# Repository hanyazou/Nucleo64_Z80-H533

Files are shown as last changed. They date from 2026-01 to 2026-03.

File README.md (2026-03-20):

# Nucleo64 Z80 H533

Nucleo64 Z80 H533 is a Z80 expansion board for the STM32 NUCLEO-H533RE that lets you run a real Z80 system with Microsoft BASIC and CP/M.

It combines a physical Z80 CPU, SRAM, and an STM32H533, which handles the I/O side at high speed.
With a microSD card, the board can boot CP/M directly, and it can even access a real USB floppy disk drive experimentally.

If you enjoy retro computers, homebrew hardware, or classic 8-bit systems, this board is a compact way to build and explore a modern Z80 machine.

Compared with the earlier <a href="https://github.com/hanyazou/Nucleo64_Z80">Nucleo64 Z80 project</a>,
this version provides faster I/O handling and adds a USB interface.

## Features

- Simple two-chip Z80 section using a Z80 CPU and SRAM
- Firmware includes Microsoft BASIC and an IPL (Initial Program Loader)
- Higher Z80 clock speed, up to 20 MHz
- microSD card over SPI for use as CP/M floppy disk images
- Experimental support for a real floppy disk drive over USB

This project is derived from satoshiokue's MEZ80RAM and SuperMEZ80-CPM.

## Appearance

The white boards shown in the following pictures are the Nucleo64 Z80 H533.

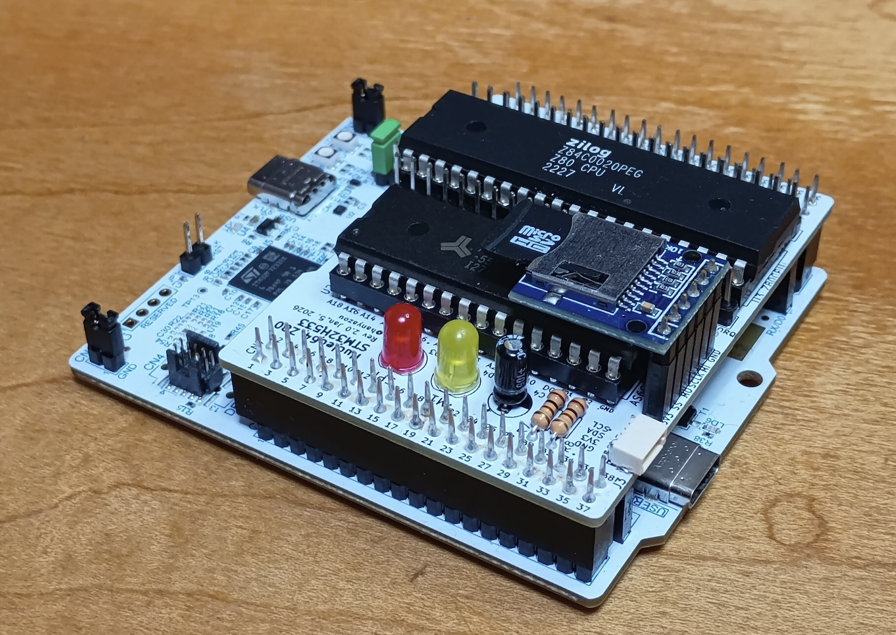
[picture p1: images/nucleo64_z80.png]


## Block Diagram



For more details, see the <a href="schematic.pdf">schematic (PDF)</a>.

## Required Components



### ICs

- U3 Z80, DIP-40, x1
- U2 AS6C4008-55 SRAM, 4 Mbit, DIP-32, x2

A Z80C0004 (4 MHz) or faster device is recommended.  
If you do not plan to run CP/M 3.0, even 512 Kbit (64 KB) SRAM may be sufficient.   

### Through-Hole Components

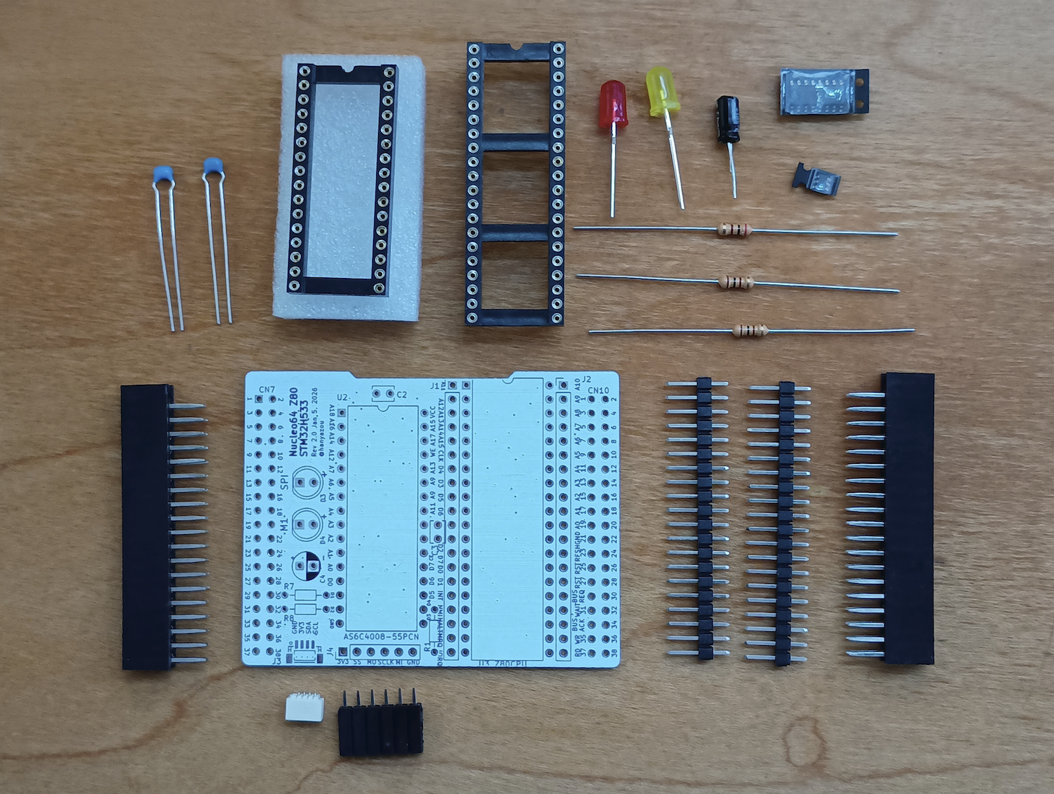
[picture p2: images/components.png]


- U3 IC socket, DIP-40
- U2 IC socket, DIP-32
- C2, C3 0.1 uF ceramic capacitors
- C4 10 uF electrolytic capacitor
- R1 200 ohm, 1/6 W resistor
- R7, R8 100 ohm, 1/4 W resistors
- D3, D4 LEDs
- CN7, CN10 2x19 female pin sockets, 0.1 inch pitch

The resistor value for R7 and R8 may need to be adjusted depending on the LEDs you use.

### Surface-Mount Components

- U4 TPS22917DBV load switch, SOT-23-6 *3
- U5 74HCT153D, SOP-16 *4
- C1, C5 0.1 uF capacitors, 0603
- R2, R3 10 k ohm resistors, 0603

*3) This load switch turns the Z80-side power on and off from the STM32H533.  
It helps prevent 5 V from feeding back into the STM32 I/O pins and potentially damaging the MCU.  
The board may still work if 5 V and VCC are tied directly together, but that carries some risk to the STM32 and is not recommended.

*4) This logic IC is used for bank switching.  
If you do not need CP/M 3.0 support, you can omit U5 and short JP1 and JP2 instead.

### Optional Components

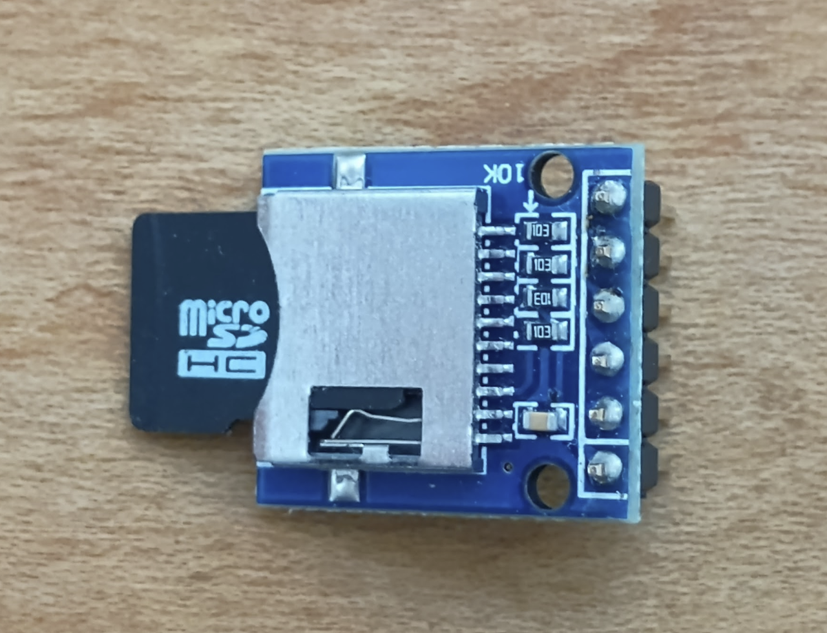
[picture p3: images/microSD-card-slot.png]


- J1, J2 1x20 pin headers, 0.1 inch pitch
- J3 JST SH 1.0 mm 4-pin connector
- J4 1x6 female pin socket, 0.1 inch pitch

J4 is for I2C Qwiic devices.  
For the microSD card slot, use the ARM/Arduino-compatible type shown on the following page:  
https://www.amazon.com/dp/B0B7WZQVHS

## Assembly Notes

With the small number of parts, assembly is straightforward.
Solder all components except the 2x19 pin headers first, then solder the pin headers last.

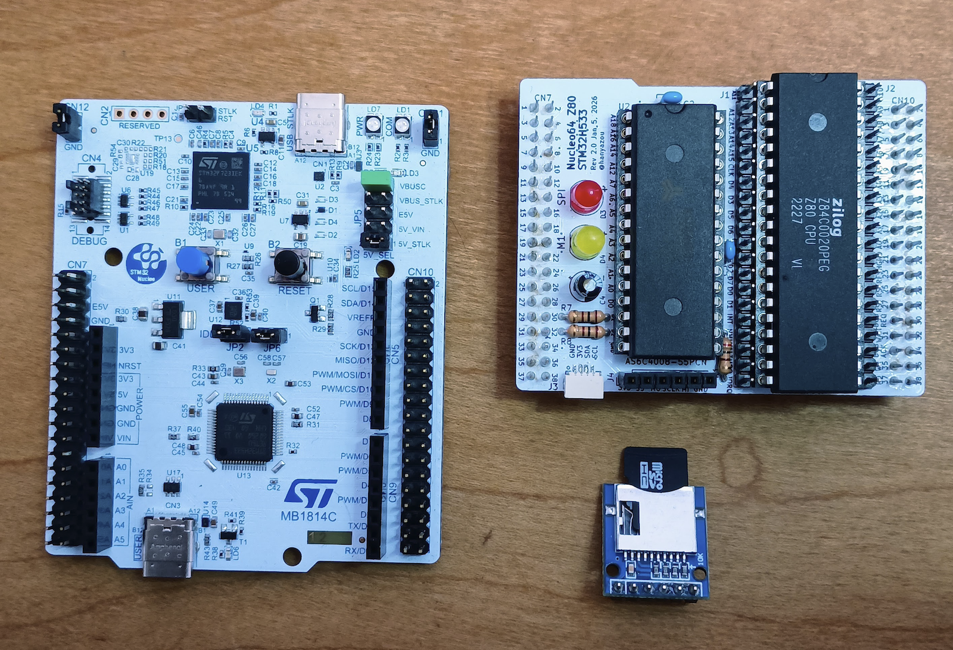
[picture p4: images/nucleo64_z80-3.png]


The 74HCT153 and TPS22917 parts I used had markings that made pin 1 orientation hard to identify.
The following photos show the orientation I used during assembly.

<p align="center">
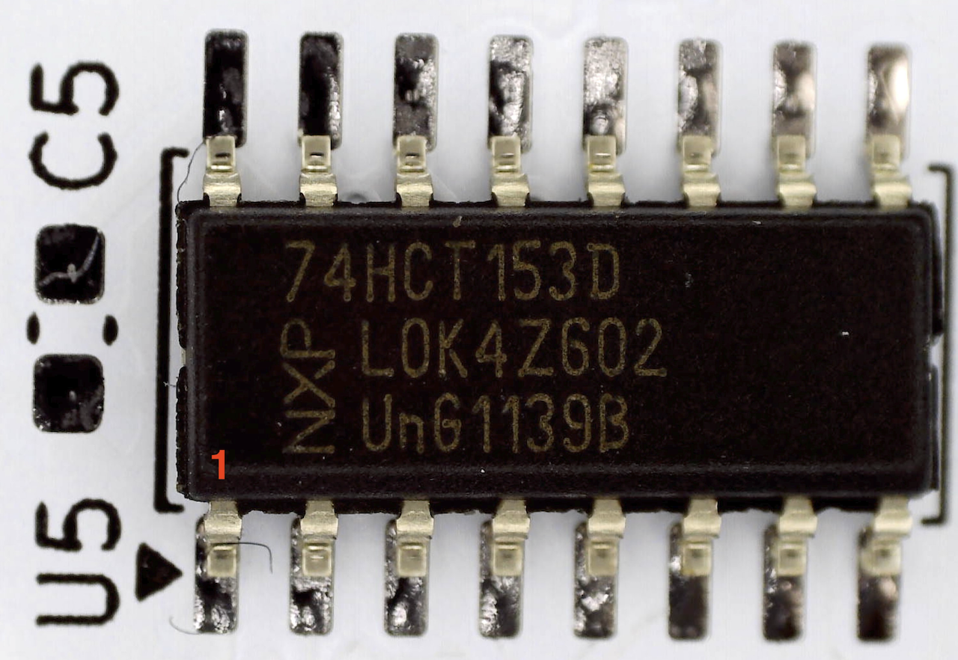
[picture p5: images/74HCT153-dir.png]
  
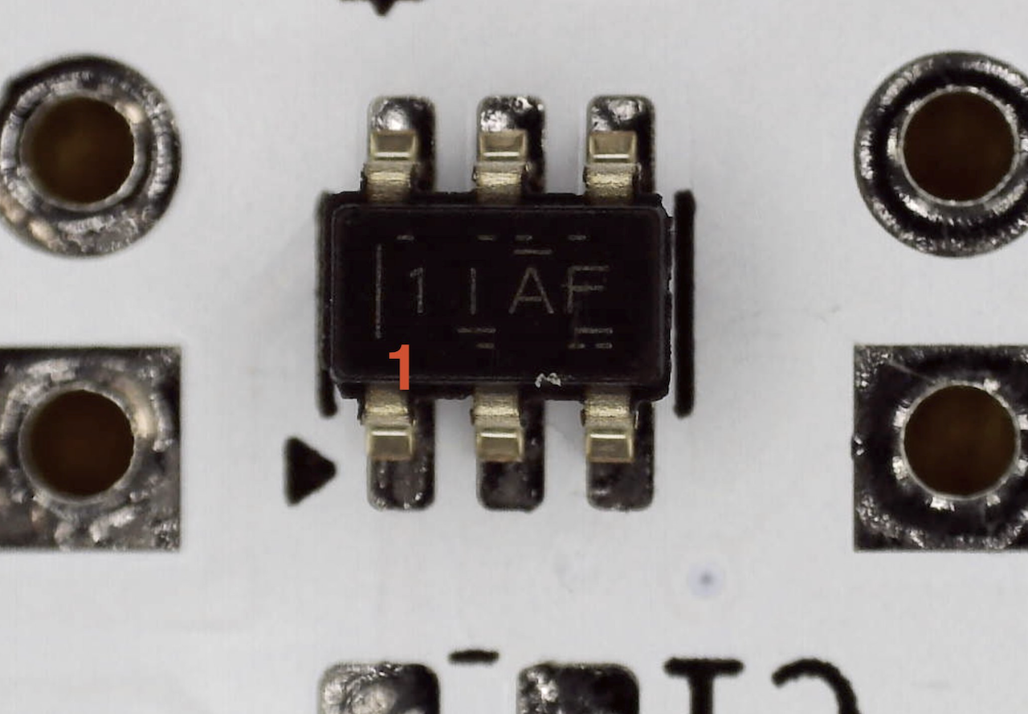
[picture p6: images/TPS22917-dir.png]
  
</p>

## NUCLEO Board Modification

ST occasionally revises Nucleo boards, and the hardware details can change slightly between revisions.
The board used here is marked:

`NUCLEO-H533RE NUH533RE$KR2 MB1814-H533RE-C02`

At the time of writing, there does not appear to be another NUCLEO-H533 variant.

On MB1814-H533RE-C02, GPIO pins PC14 and PC15 are connected to the OSC32 low-speed clock circuitry and are not routed to the Morpho connectors by default.
This project uses PC14 and PC15, so you need to rework the solder bridges:

- Remove SB30 and SB31
- Bridge SB29 and SB32

<p align="center">
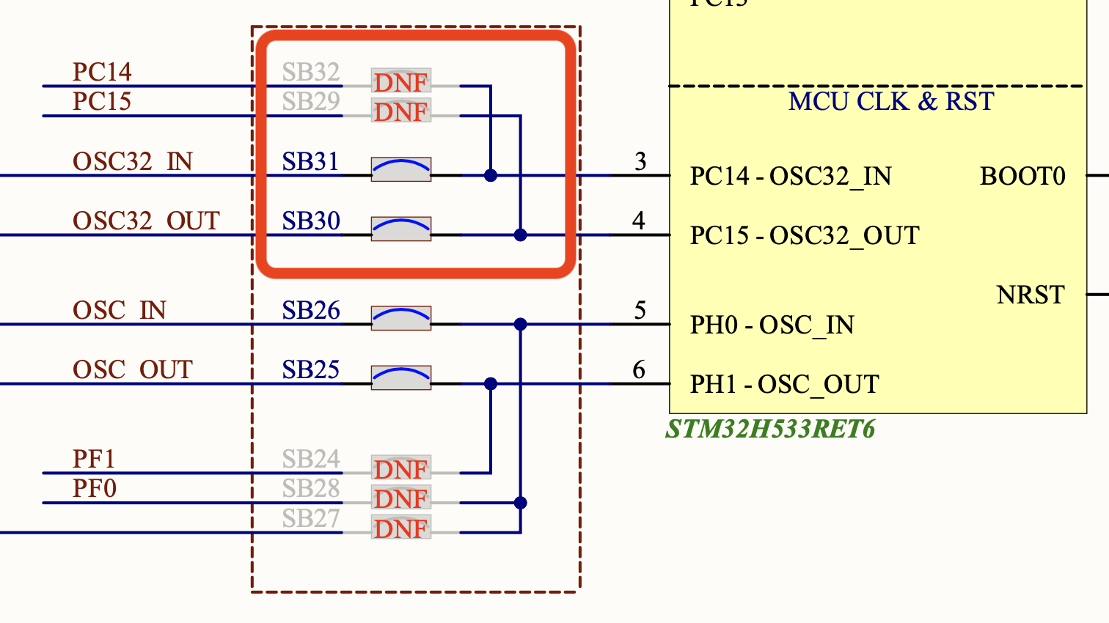
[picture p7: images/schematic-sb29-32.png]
  
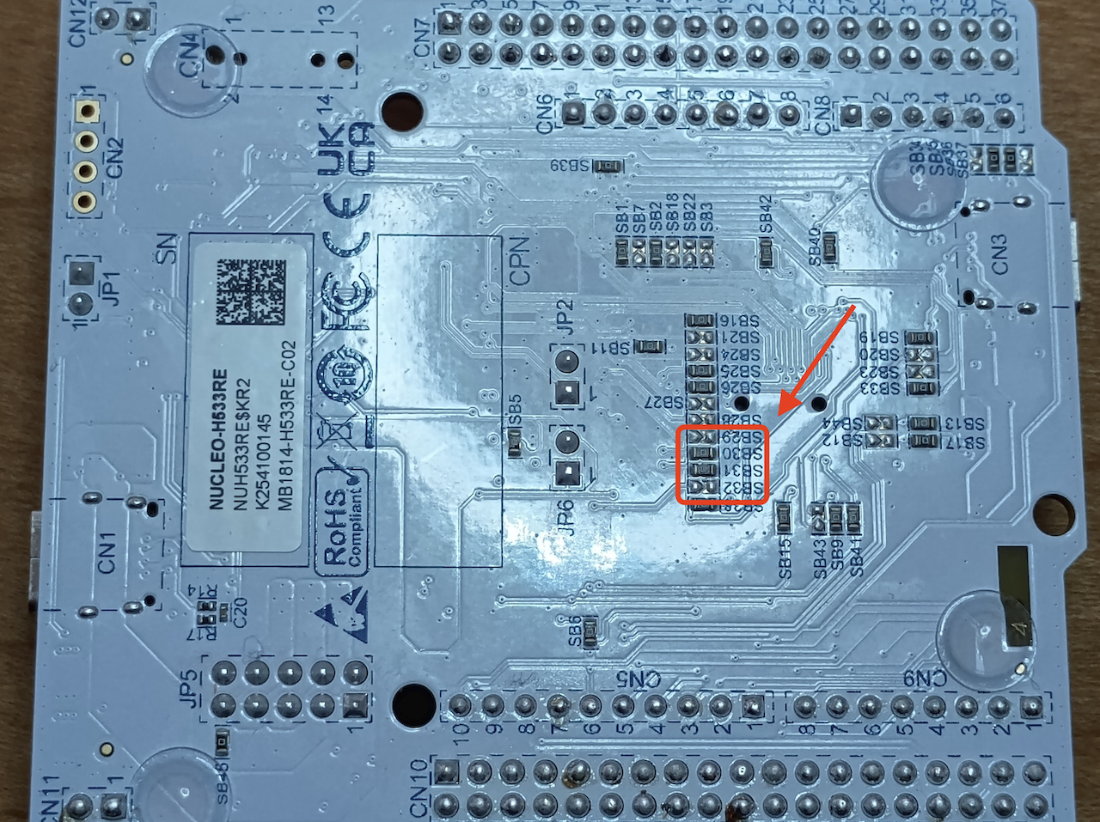
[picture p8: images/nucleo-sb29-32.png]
  
</p>

## Board Firmware

The `FW/projects/h533re` folder contains a STM32 firmware project for STM32CubeIDE.
The current target is the NUCLEO-H533RE.

The firmware includes Microsoft BASIC and an IPL.

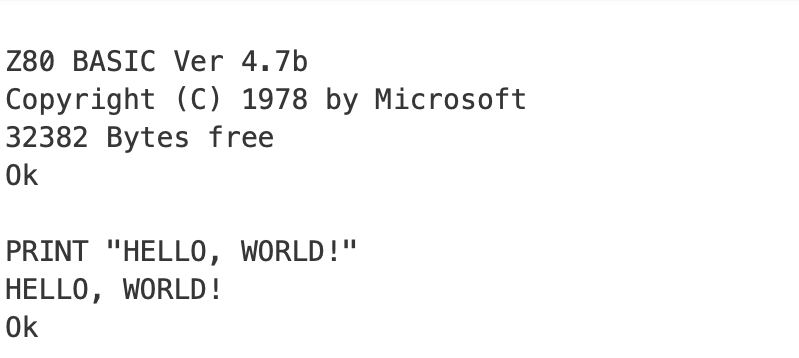
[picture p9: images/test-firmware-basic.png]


### Change Z80 clock speed

The Z80 clock is generated by TIM2 in the STM32H533.
With a 248 MHz timer clock and a TIM2 counter period of 247, the output clock is 1 MHz, so the Z80 runs at 1 MHz.

If you change the counter period to 12, the Z80 clock becomes about 20 MHz.
In that case, the pulse value should be set to half of the counter period.
At 20 MHz, running `ASCIIARTM.BAS` takes about 60 seconds.

<p align="center">
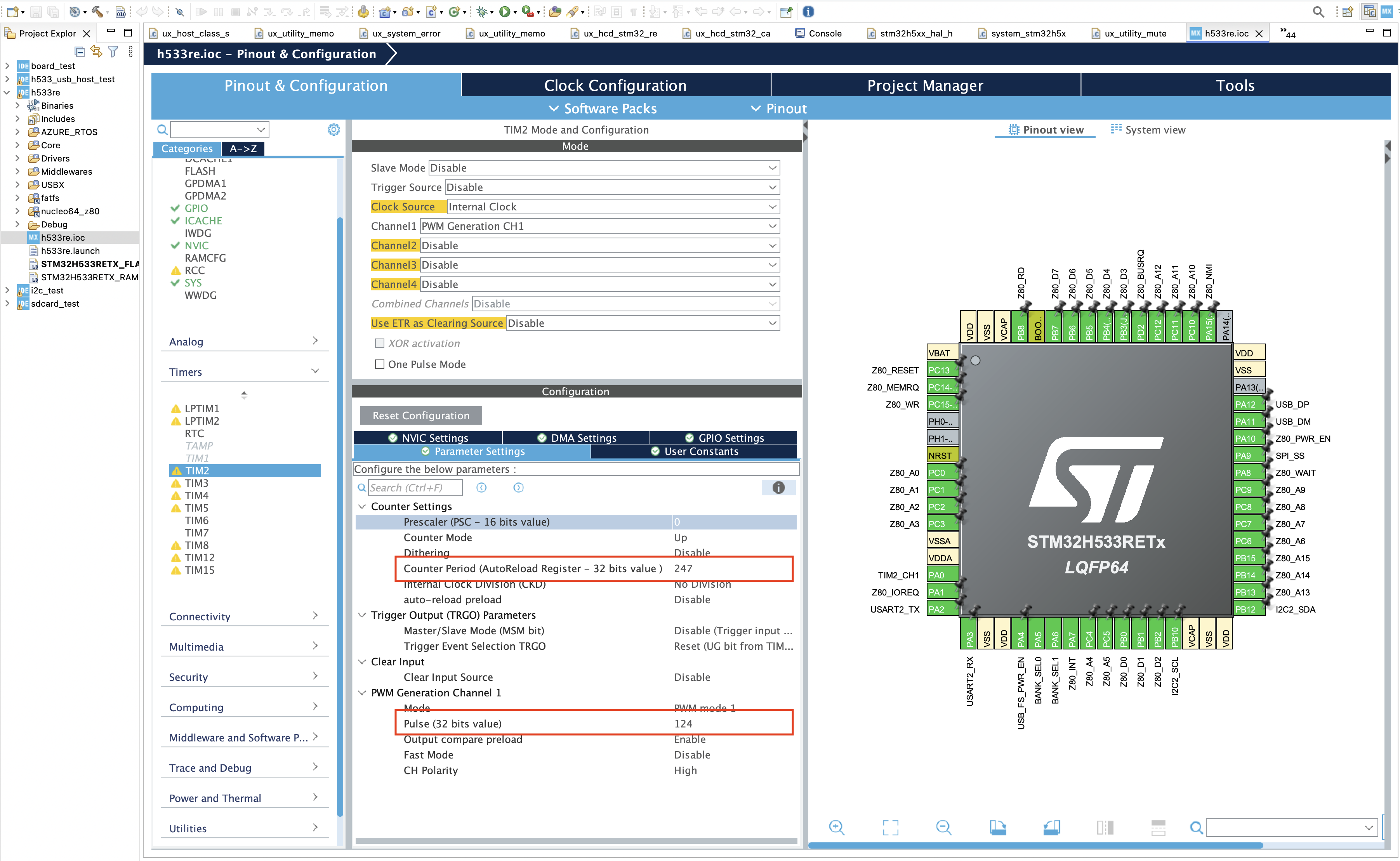
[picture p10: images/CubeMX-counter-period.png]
  
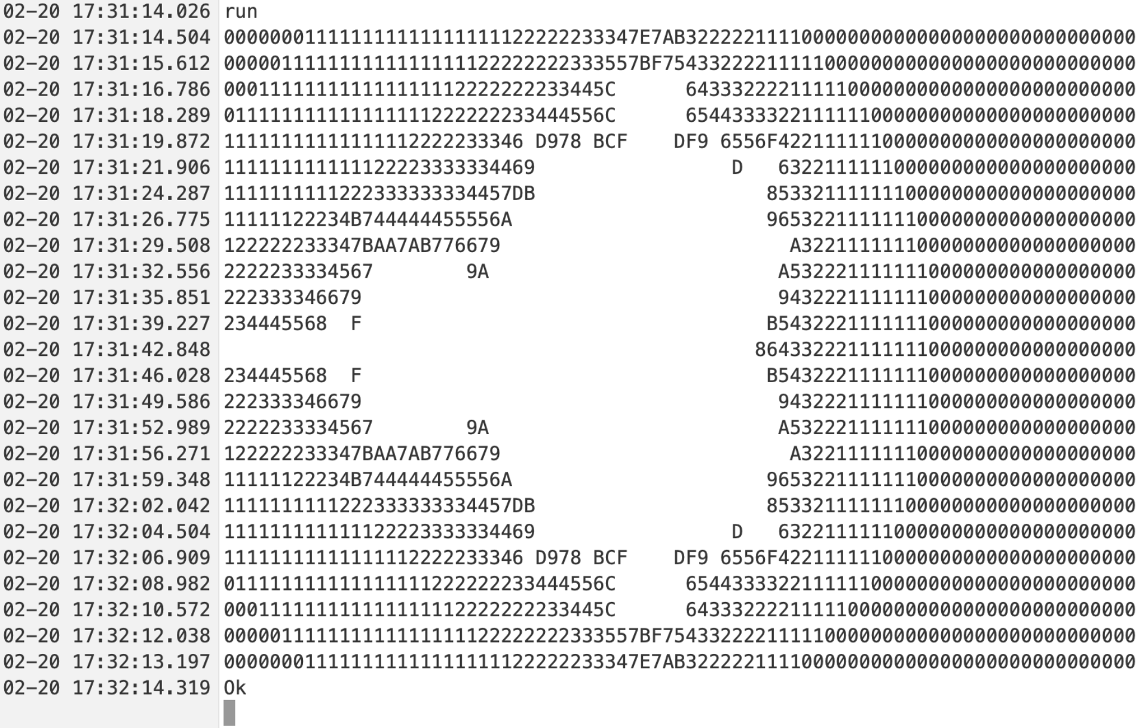
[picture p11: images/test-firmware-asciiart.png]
  
</p>

## Booting CP/M

You can run CP/M on the Z80 by connecting a microSD card slot to the SPI interface, writing a CP/M-80 disk image to the microSD card, and booting the board with that card inserted.

The disk images from <a href="https://github.com/hanyazou/SuperMEZ80">hanyazou/SuperMEZ80</a> can be used as-is.

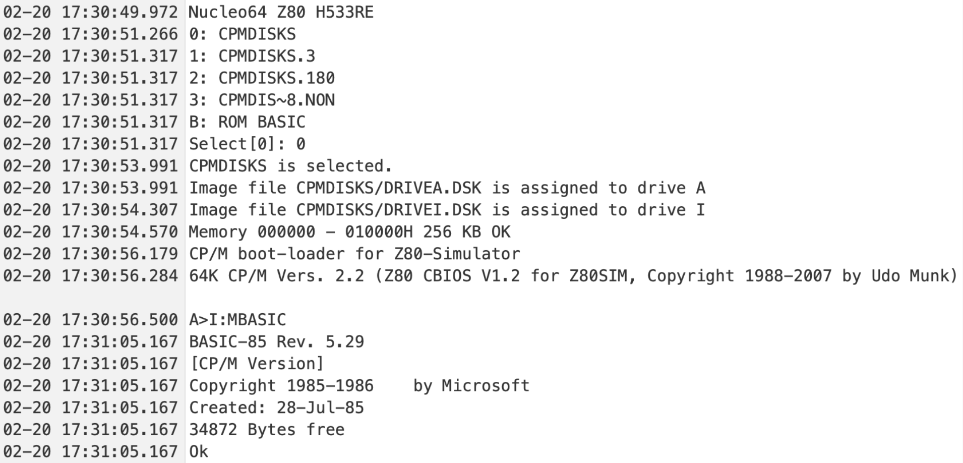
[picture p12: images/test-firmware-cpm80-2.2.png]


## Connecting a Floppy Disk Drive

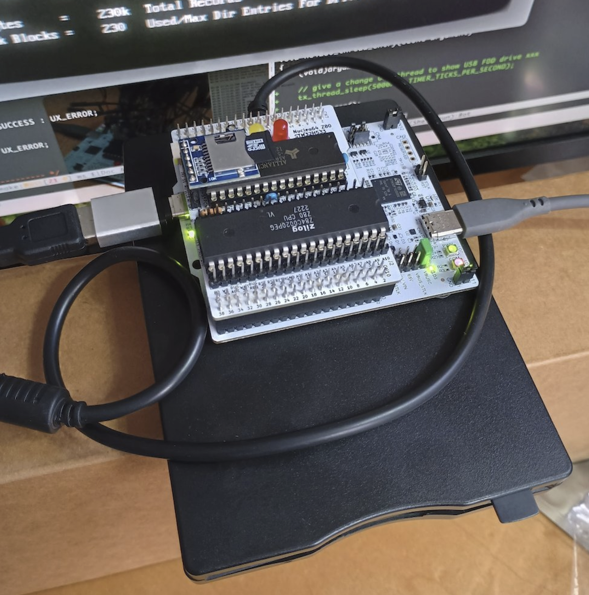
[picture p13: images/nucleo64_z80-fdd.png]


The STM32H533 has USB host capability.
In the photo above, a USB floppy disk drive is connected to the Nucleo board, and CP/M-80 is accessing the floppy disk.

Video: <a href="https://www.youtube.com/watch?v=yQrmxK0HUM0">YouTube</a>

In that video, CP/M boots from the microSD card as drive A:, and then displays the file list on the floppy disk drive assigned as drive C:.
You can also hear the drive access sounds.

The NUCLEO-H533RE board does not explicitly advertise USB host support, but it can operate as a USB host if 5 V is supplied to VBUS at the user USB connector.

The firmware has been tested experimentally with the following USB floppy disk drive, purchased from
<a href="https://amzn.asia/d/04LAehW9">Amazon.co.jp</a>:

- TEAC USB floppy disk drive
- Current support is read-only

```
Device VendorID/ProductID: 0x0644/0x0000 (TEAC Corporation)
Manufacturer String:      1 "TEACV0.0"
Product String:           2 "TEACV0.0"
```

To supply 5 V to VBUS from the USB Type-C connector, short both settings in the NUCLEO power source selection header `JP5`:

- `5V_STLK` to power the STM32 side from the ST-LINK 5 V supply
- `VBUSC` to route power to the user USB connector `CN3`

With both jumpers set, the ST-LINK 5 V supply is fed to `CN3` VBUS.

Be careful here: if you connect `CN3` to a PC or any other device that also drives 5 V onto VBUS in this configuration, you could damage the Nucleo board, the connected device, or both.
Do not connect `CN3` to a host PC while this power configuration is in place.

<p align="center">
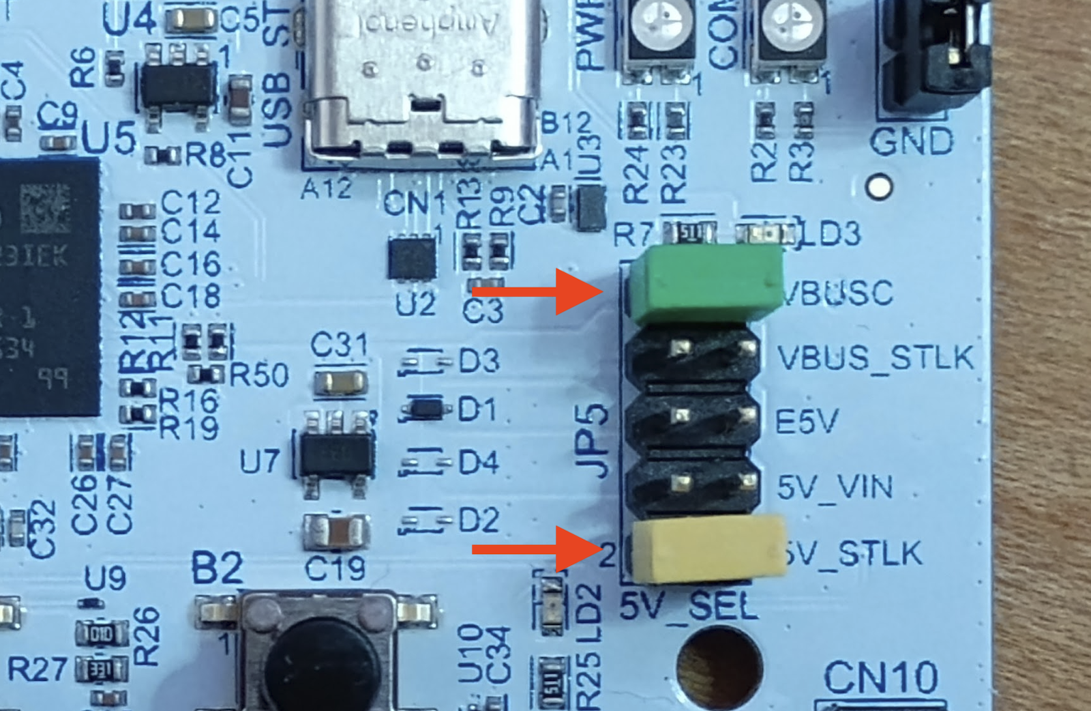
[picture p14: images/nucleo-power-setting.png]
  
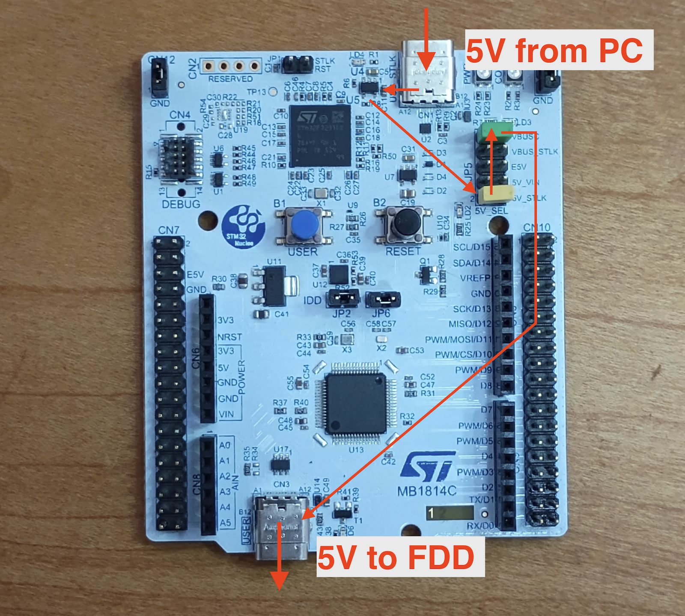
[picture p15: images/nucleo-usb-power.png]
  
</p>

## References

### SuperMEZ80-CPM

https://github.com/hanyazou/SuperMEZ80-CPM

### EMUZ80

https://vintagechips.wordpress.com/2022/03/05/emuz80_reference/

### MEZ80RAM

https://github.com/satoshiokue/MEZ80RAM

### Nucleo STM32H533RE

#### Board

https://www.st.com/en/evaluation-tools/nucleo-h533re.html

#### Schematic

<a href="https://www.st.com/content/ccc/resource/technical/layouts_and_diagrams/schematic_pack/group2/58/61/64/9a/03/20/4f/84/mb1814-h533re-c02-schematic/files/mb1814-h533re-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">MB1814</a>

#### User Manual

<a href="https://www.st.com/content/ccc/resource/technical/document/user_manual/group2/86/81/52/e6/5d/f1/46/9e/DM00941891/files/DM00941891.pdf/jcr:content/translations/en.DM0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">UM3121</a>

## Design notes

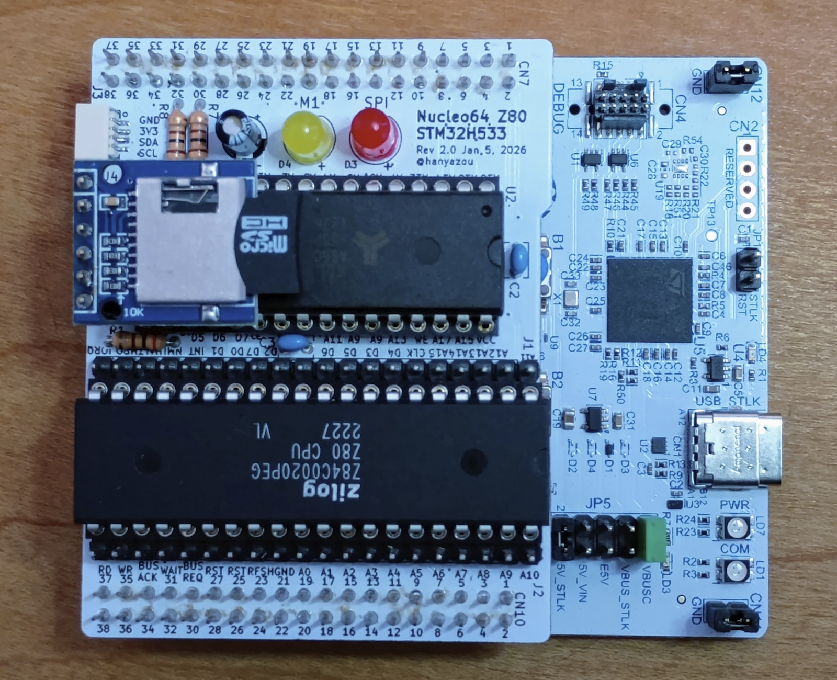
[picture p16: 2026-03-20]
images/nucleo64_z80-2.png

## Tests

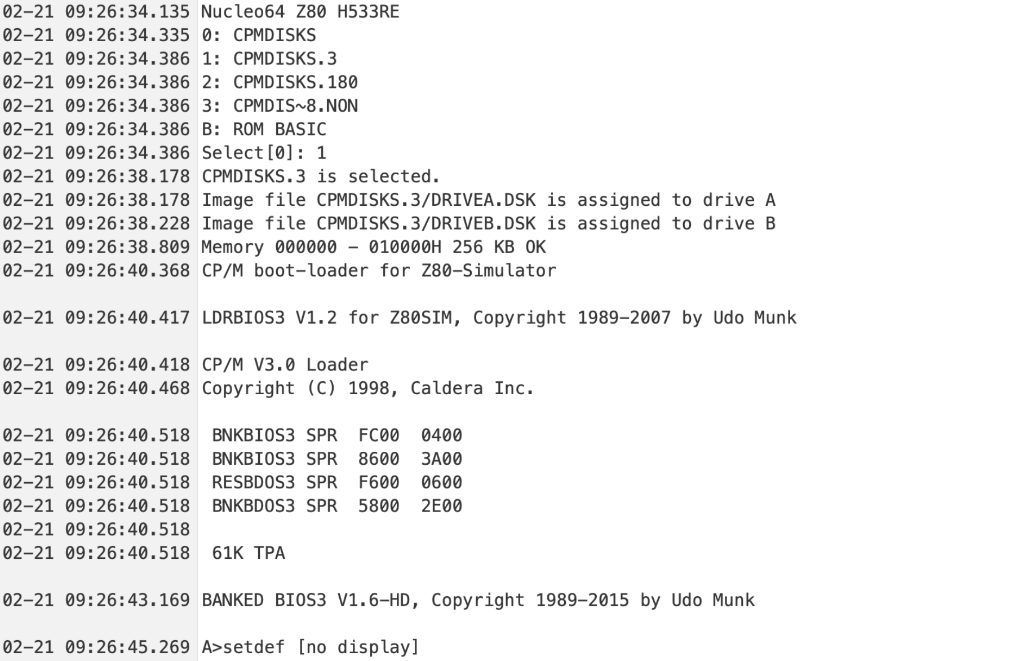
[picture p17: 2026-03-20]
images/test-firmware-cpm80-3.0.png

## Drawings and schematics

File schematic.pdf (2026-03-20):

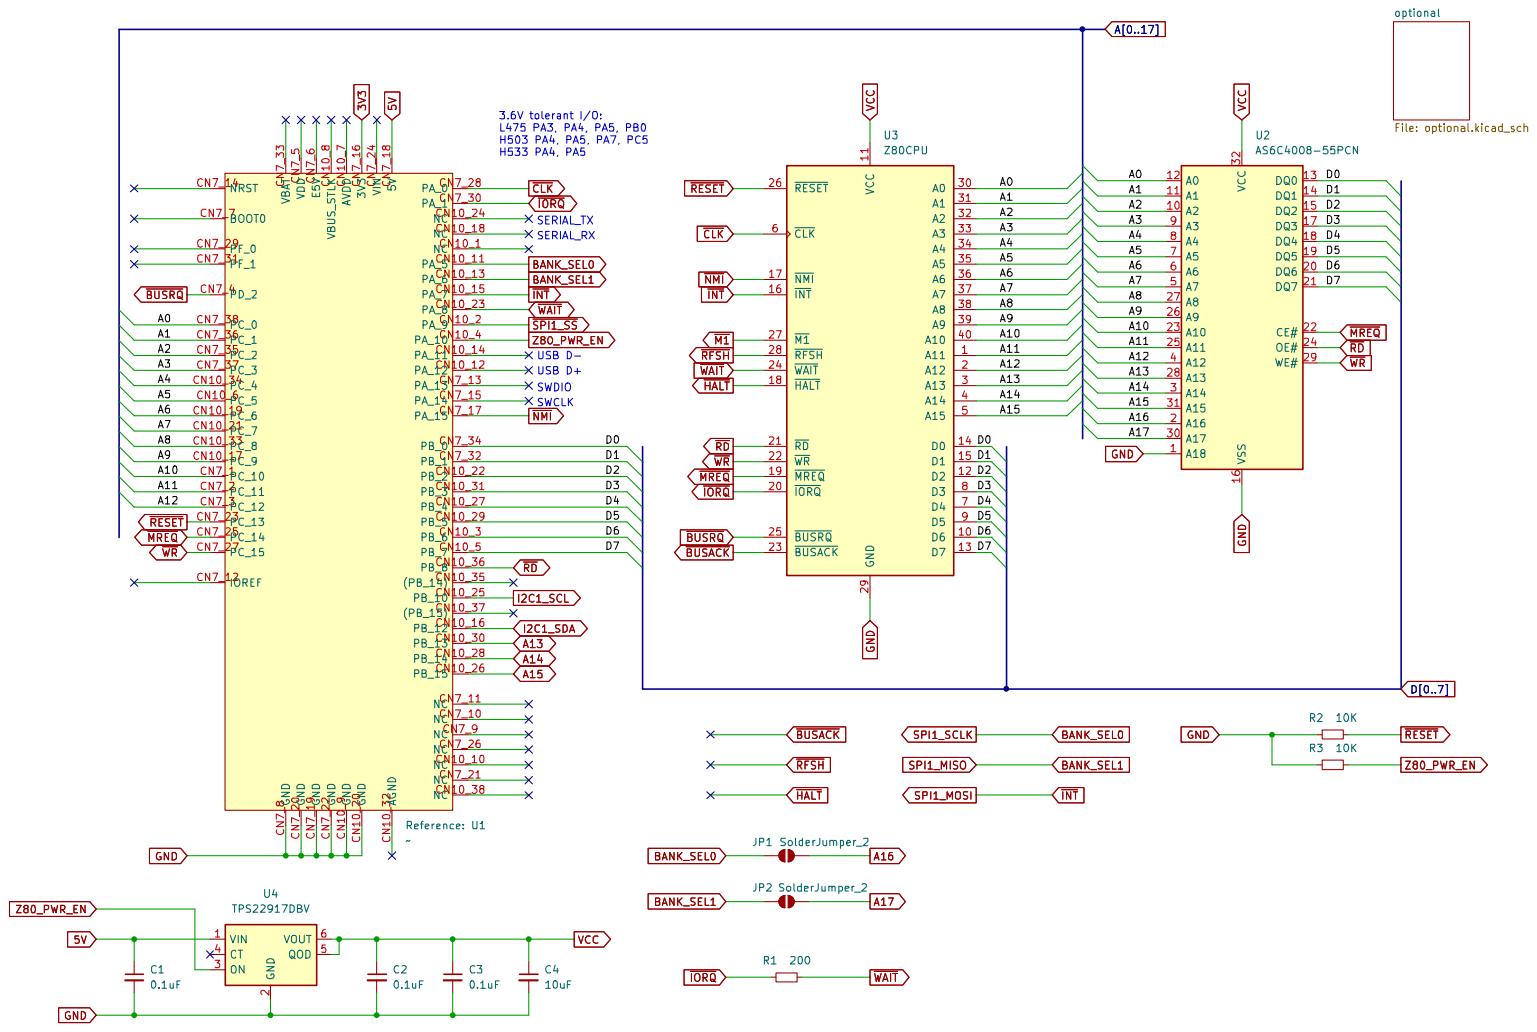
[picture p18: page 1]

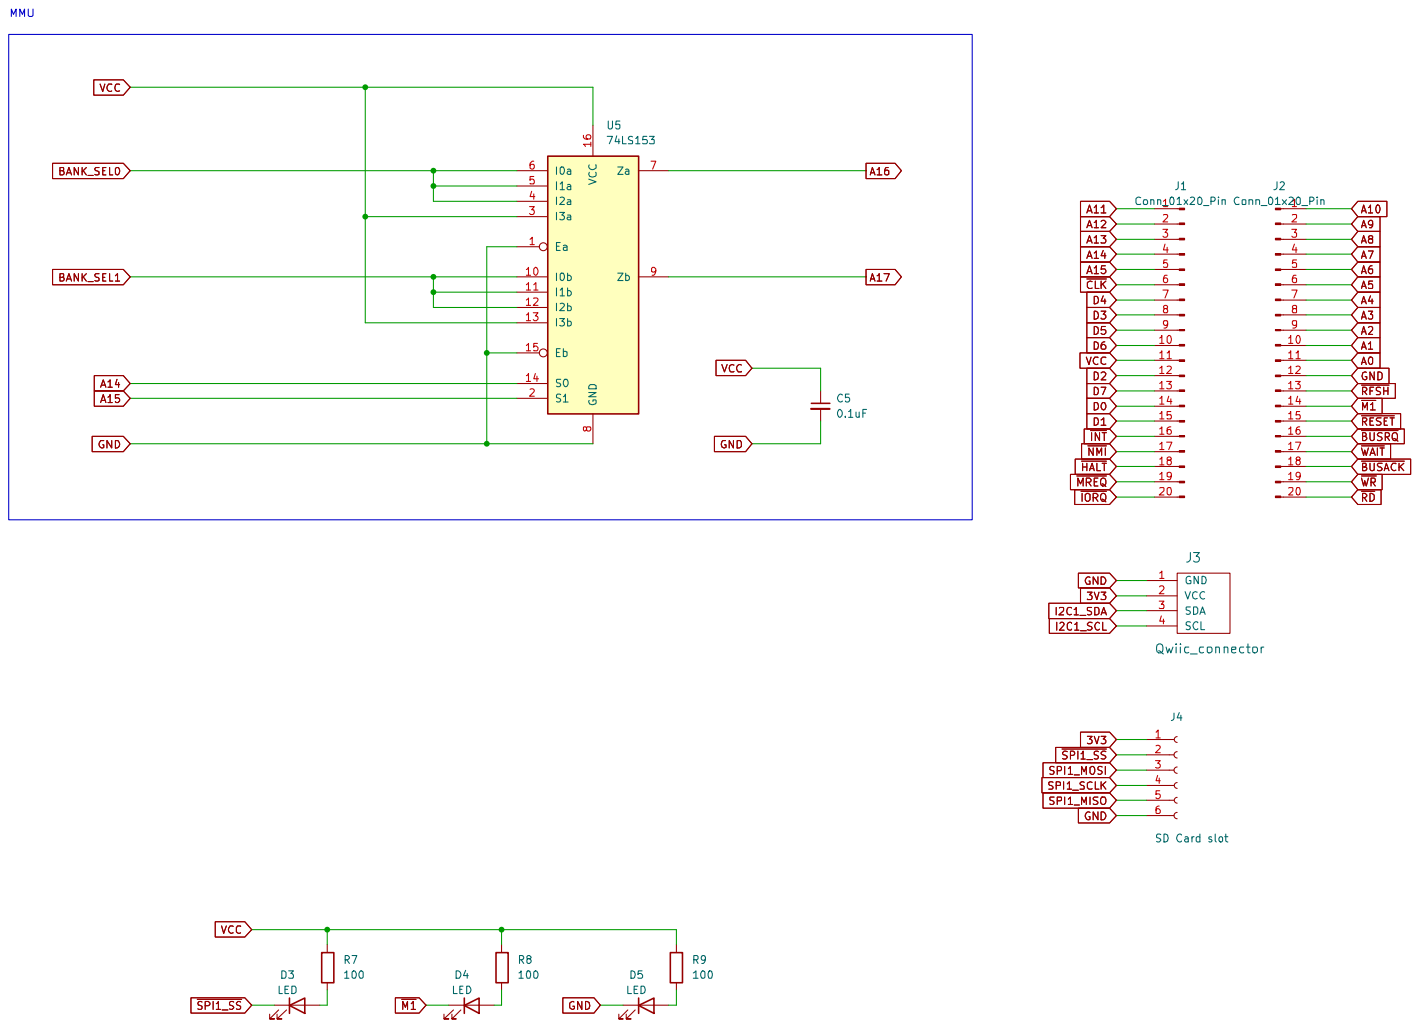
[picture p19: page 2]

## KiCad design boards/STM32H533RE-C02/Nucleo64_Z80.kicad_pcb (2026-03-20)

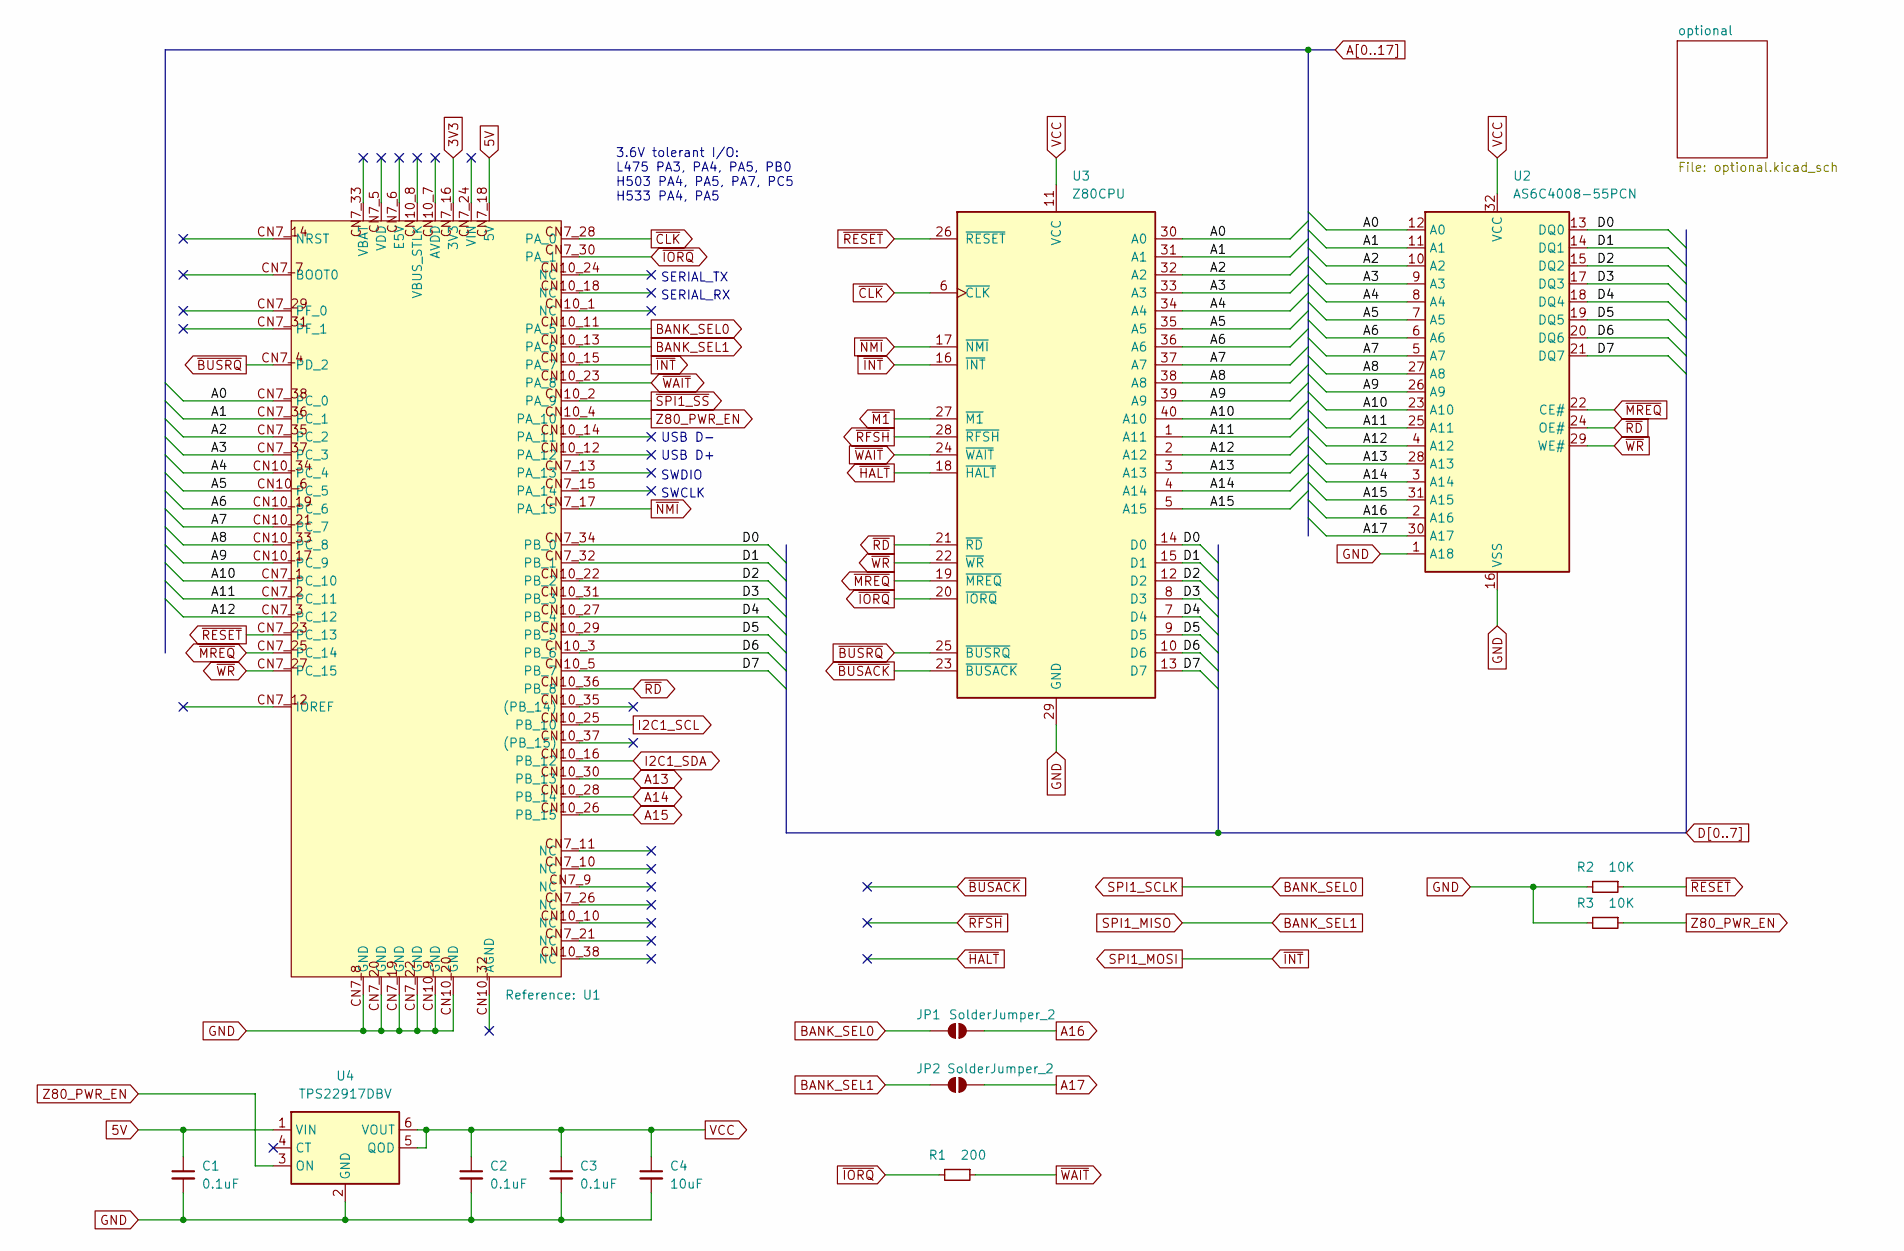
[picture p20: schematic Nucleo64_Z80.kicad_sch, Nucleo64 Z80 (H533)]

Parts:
C1: 0.1uF; C_0603_1608Metric_Pad1.08x0.95mm_HandSolder
C2, C3: 0.1uF; C_Disc_D3.8mm_W2.6mm_P2.50mm
C4: 10uF; CP_Radial_D5.0mm_P2.50mm
JP1, JP2: SolderJumper_2; SolderJumper-2_P1.3mm_Open_TrianglePad1.0x1.5mm
R1: 200; R_Axial_DIN0204_L3.6mm_D1.6mm_P7.62mm_Horizontal
R2, R3: 10K; R_0603_1608Metric_Pad0.98x0.95mm_HandSolder
U1: NUCLEO64_morpho
U2: AS6C4008-55PCN; DIP-32_W15.24mm
U3: Z80CPU; DIP-40_W15.24mm
U4: TPS22917DBV; SOT-23-6

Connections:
3V3: U1.CN7_16 (3V3); also elsewhere on the board
5V: C1.1, U1.CN7_18 (5V), U4.1 (VIN)
A0: U1.CN7_38 (PC_0), U2.12 (A0), U3.30 (A0); also elsewhere on the board
A1: U1.CN7_36 (PC_1), U2.11 (A1), U3.31 (A1); also elsewhere on the board
A2: U1.CN7_35 (PC_2), U2.10 (A2), U3.32 (A2); also elsewhere on the board
A3: U1.CN7_37 (PC_3), U2.9 (A3), U3.33 (A3); also elsewhere on the board
A4: U1.CN10_34 (PC_4), U2.8 (A4), U3.34 (A4); also elsewhere on the board
A5: U1.CN10_6 (PC_5), U2.7 (A5), U3.35 (A5); also elsewhere on the board
A6: U1.CN10_19 (PC_6), U2.6 (A6), U3.36 (A6); also elsewhere on the board
A7: U1.CN10_21 (PC_7), U2.5 (A7), U3.37 (A7); also elsewhere on the board
A8: U1.CN10_33 (PC_8), U2.27 (A8), U3.38 (A8); also elsewhere on the board
A9: U1.CN10_17 (PC_9), U2.26 (A9), U3.39 (A9); also elsewhere on the board
A10: U1.CN7_1 (PC_10), U2.23 (A10), U3.40 (A10); also elsewhere on the board
A11: U1.CN7_2 (PC_11), U2.25 (A11), U3.1 (A11); also elsewhere on the board
A12: U1.CN7_3 (PC_12), U2.4 (A12), U3.2 (A12); also elsewhere on the board
A13: U1.CN10_30 (PB_13), U2.28 (A13), U3.3 (A13); also elsewhere on the board
A14: U1.CN10_28 (PB_14), U2.3 (A14), U3.4 (A14); also elsewhere on the board
A15: U1.CN10_26 (PB_15), U2.31 (A15), U3.5 (A15); also elsewhere on the board
A16: JP1.2 (B), U2.2 (A16); also elsewhere on the board
A17: JP2.2 (B), U2.30 (A17); also elsewhere on the board
BANK_SEL0: JP1.1 (A), U1.CN10_11 (PA_5); also elsewhere on the board
BANK_SEL1: JP2.1 (A), U1.CN10_13 (PA_6); also elsewhere on the board
D0: U1.CN7_34 (PB_0), U2.13 (DQ0), U3.14 (D0); also elsewhere on the board
D1: U1.CN7_32 (PB_1), U2.14 (DQ1), U3.15 (D1); also elsewhere on the board
D2: U1.CN10_22 (PB_2), U2.15 (DQ2), U3.12 (D2); also elsewhere on the board
D3: U1.CN10_31 (PB_3), U2.17 (DQ3), U3.8 (D3); also elsewhere on the board
D4: U1.CN10_27 (PB_4), U2.18 (DQ4), U3.7 (D4); also elsewhere on the board
D5: U1.CN10_29 (PB_5), U2.19 (DQ5), U3.9 (D5); also elsewhere on the board
D6: U1.CN10_3 (PB_6), U2.20 (DQ6), U3.10 (D6); also elsewhere on the board
D7: U1.CN10_5 (PB_7), U2.21 (DQ7), U3.13 (D7); also elsewhere on the board
GND: C1.2, C2.2, C3.2, C4.2, R2.2, R3.2, U1.CN7_8 (GND), U1.CN7_19 (GND), U1.CN7_20 (GND), U1.CN7_22 (GND), U1.CN10_9 (GND), U1.CN10_20 (GND), U2.1 (A18), U2.16 (VSS), U3.29 (GND), U4.2 (GND); also elsewhere on the board
I2C1_SCL: U1.CN10_25 (PB_10); also elsewhere on the board
I2C1_SDA: U1.CN10_16 (PB_12); also elsewhere on the board
SPI1_MOSI: U1.CN10_15 (PA_7), U3.16 (~INT); also elsewhere on the board
VCC: C2.1, C3.1, C4.1, U2.32 (VCC), U3.11 (VCC), U4.5 (QOD), U4.6 (VOUT); also elsewhere on the board
Z80_PWR_EN: R3.1, U1.CN10_4 (PA_10), U4.3 (ON)
~BUSACK: U3.23 (~BUSACK); also elsewhere on the board
~BUSRQ: U1.CN7_4 (PD_2), U3.25 (~BUSRQ); also elsewhere on the board
~CLK: U1.CN7_28 (PA_0), U3.6 (~CLK); also elsewhere on the board
~HALT: U3.18 (~HALT); also elsewhere on the board
~IORQ: R1.2, U1.CN7_30 (PA_1), U3.20 (~IORQ); also elsewhere on the board
~M1: U3.27 (~M1); also elsewhere on the board
~MREQ: U1.CN7_25 (PC_14), U2.22 (CE#), U3.19 (~MREQ); also elsewhere on the board
~NMI: U1.CN7_17 (PA_15), U3.17 (~NMI); also elsewhere on the board
~RD: U1.CN10_36 (PB_8), U2.24 (OE#), U3.21 (~RD); also elsewhere on the board
~RESET: R2.1, U1.CN7_23 (PC_13), U3.26 (~RESET); also elsewhere on the board
~RFSH: U3.28 (~RFSH); also elsewhere on the board
~SPI1_SS: U1.CN10_2 (PA_9); also elsewhere on the board
~WAIT: R1.1, U1.CN10_23 (PA_8), U3.24 (~WAIT); also elsewhere on the board
~WR: U1.CN7_27 (PC_15), U2.29 (WE#), U3.22 (~WR); also elsewhere on the board

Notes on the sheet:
SWDIO
SERIAL_RX
USB D+
USB D-
SERIAL_TX
SWCLK
3.6V tolerant I/O: L475 PA3, PA4, PA5, PB0 H503 PA4, PA5, PA7, PC5 H533 PA4, PA5

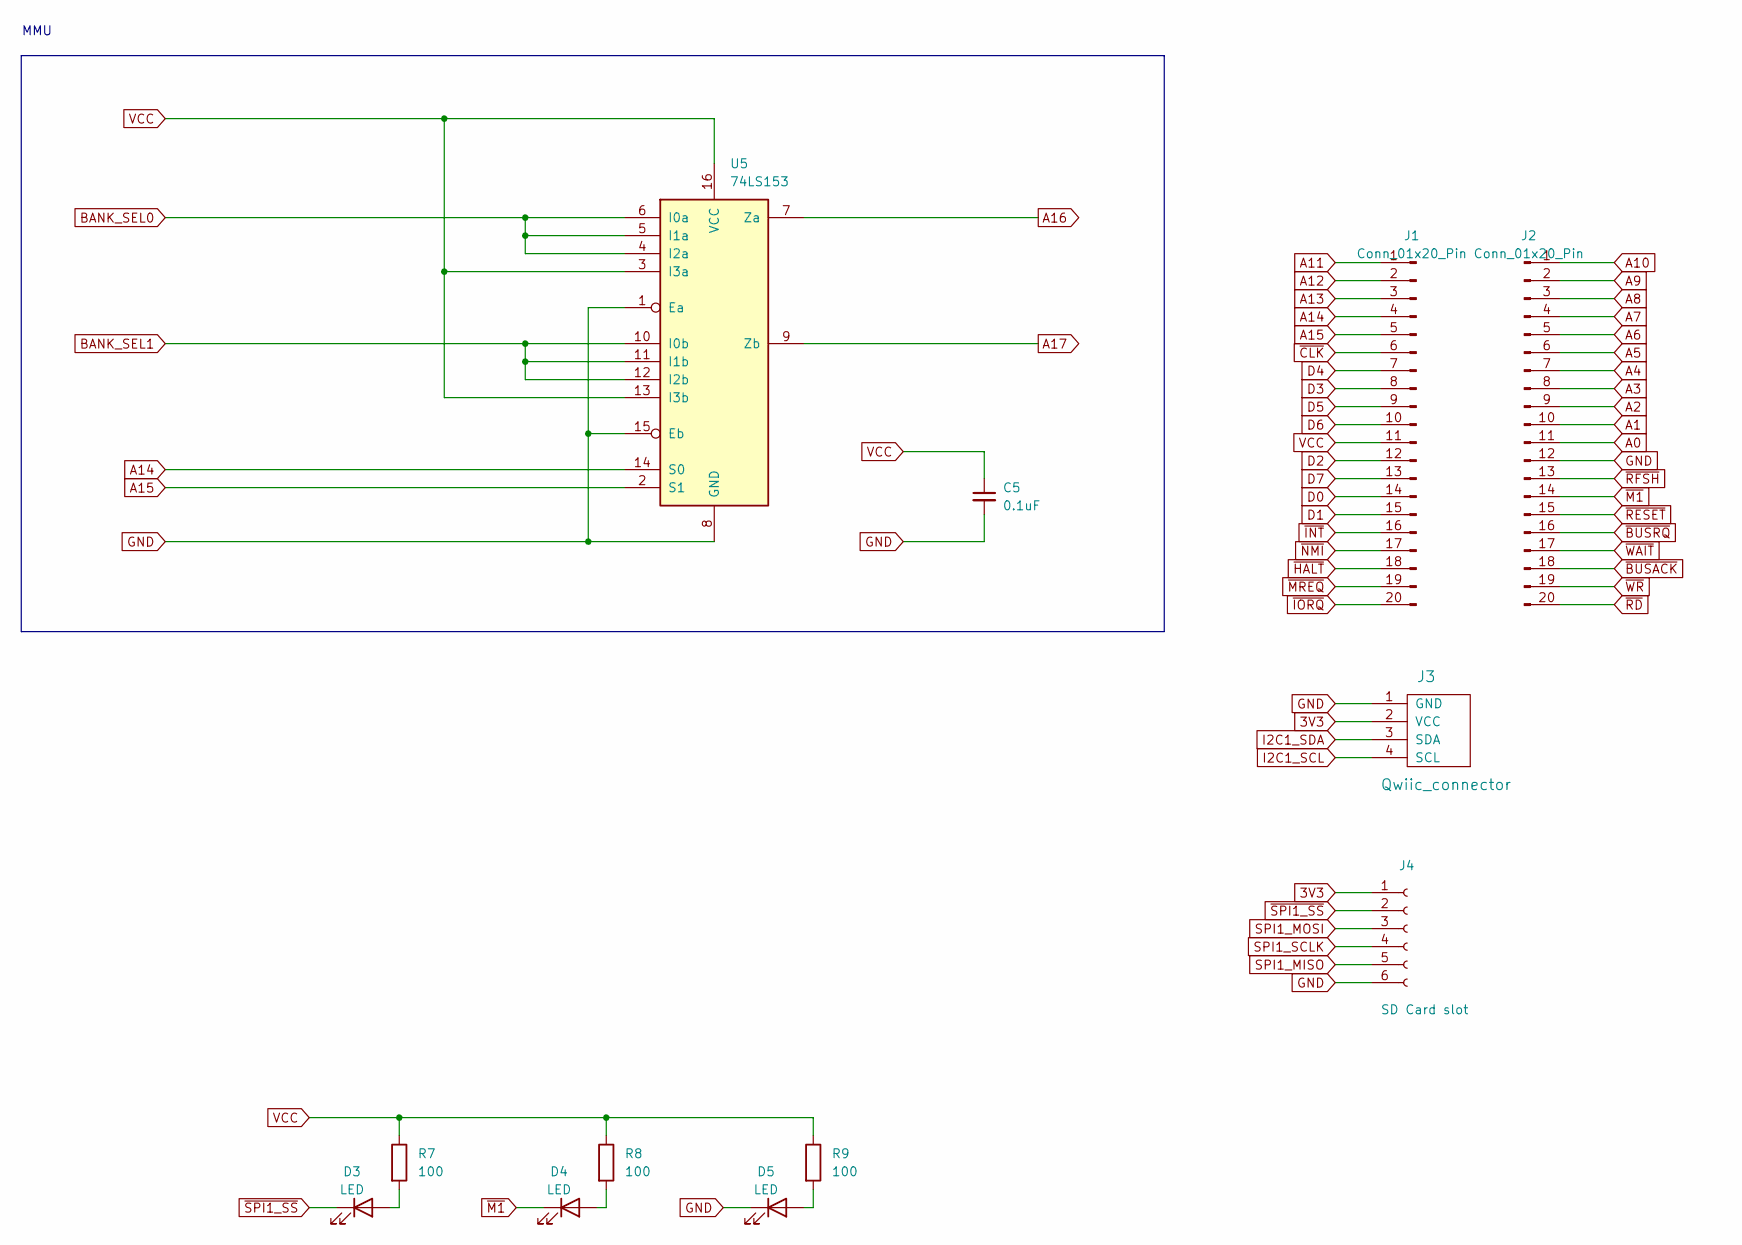
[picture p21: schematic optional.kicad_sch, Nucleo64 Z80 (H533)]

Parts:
C5: 0.1uF; C_0603_1608Metric_Pad1.08x0.95mm_HandSolder
D3, D4, D5: LED; LED_D5.0mm
J1, J2: Conn_01x20_Pin; PinHeader_1x20_P2.54mm_Vertical
J3: Qwiic_connector; Qwiic_I2C_1.00mm_4pin
J4: SD Card slot; PinHeader_1x06_P2.54mm_Vertical
R7, R8, R9: 100; R_Axial_DIN0204_L3.6mm_D1.6mm_P7.62mm_Horizontal
U5: 74LS153; SOP-16_4.55x10.3mm_P1.27mm

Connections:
3V3: J3.2 (VCC), J4.1; also elsewhere on the board
A0: J2.11; also elsewhere on the board
A1: J2.10; also elsewhere on the board
A2: J2.9; also elsewhere on the board
A3: J2.8; also elsewhere on the board
A4: J2.7; also elsewhere on the board
A5: J2.6; also elsewhere on the board
A6: J2.5; also elsewhere on the board
A7: J2.4; also elsewhere on the board
A8: J2.3; also elsewhere on the board
A9: J2.2; also elsewhere on the board
A10: J2.1; also elsewhere on the board
A11: J1.1; also elsewhere on the board
A12: J1.2; also elsewhere on the board
A13: J1.3; also elsewhere on the board
A14: J1.4, U5.14 (S0); also elsewhere on the board
A15: J1.5, U5.2 (S1); also elsewhere on the board
A16: U5.7 (Za); also elsewhere on the board
A17: U5.9 (Zb); also elsewhere on the board
BANK_SEL0: J4.4, U5.4 (I2a), U5.5 (I1a), U5.6 (I0a); also elsewhere on the board
BANK_SEL1: J4.5, U5.10 (I0b), U5.11 (I1b), U5.12 (I2b); also elsewhere on the board
D0: J1.14; also elsewhere on the board
D1: J1.15; also elsewhere on the board
D2: J1.12; also elsewhere on the board
D3: J1.8; also elsewhere on the board
D4: J1.7; also elsewhere on the board
D5: J1.9; also elsewhere on the board
D6: J1.10; also elsewhere on the board
D7: J1.13; also elsewhere on the board
GND: C5.2, D5.1 (K), J2.12, J3.1 (GND), J3.6, J4.6, U5.1 (Ea), U5.8 (GND), U5.15 (Eb); also elsewhere on the board
I2C1_SCL: J3.4 (SCL); also elsewhere on the board
I2C1_SDA: J3.3 (SDA); also elsewhere on the board
unnamed: D3.2 (A), R7.2
unnamed: D4.2 (A), R8.2
unnamed: D5.2 (A), R9.2
SPI1_MOSI: J1.16, J4.3; also elsewhere on the board
VCC: C5.1, J1.11, R7.1, R8.1, R9.1, U5.3 (I3a), U5.13 (I3b), U5.16 (VCC); also elsewhere on the board
~BUSACK: J2.18; also elsewhere on the board
~BUSRQ: J2.16; also elsewhere on the board
~CLK: J1.6; also elsewhere on the board
~HALT: J1.18; also elsewhere on the board
~IORQ: J1.20; also elsewhere on the board
~M1: D4.1 (K), J2.14; also elsewhere on the board
~MREQ: J1.19; also elsewhere on the board
~NMI: J1.17; also elsewhere on the board
~RD: J2.20; also elsewhere on the board
~RESET: J2.15; also elsewhere on the board
~RFSH: J2.13; also elsewhere on the board
~SPI1_SS: D3.1 (K), J4.2; also elsewhere on the board
~WAIT: J2.17; also elsewhere on the board
~WR: J2.19; also elsewhere on the board

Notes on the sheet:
MMU

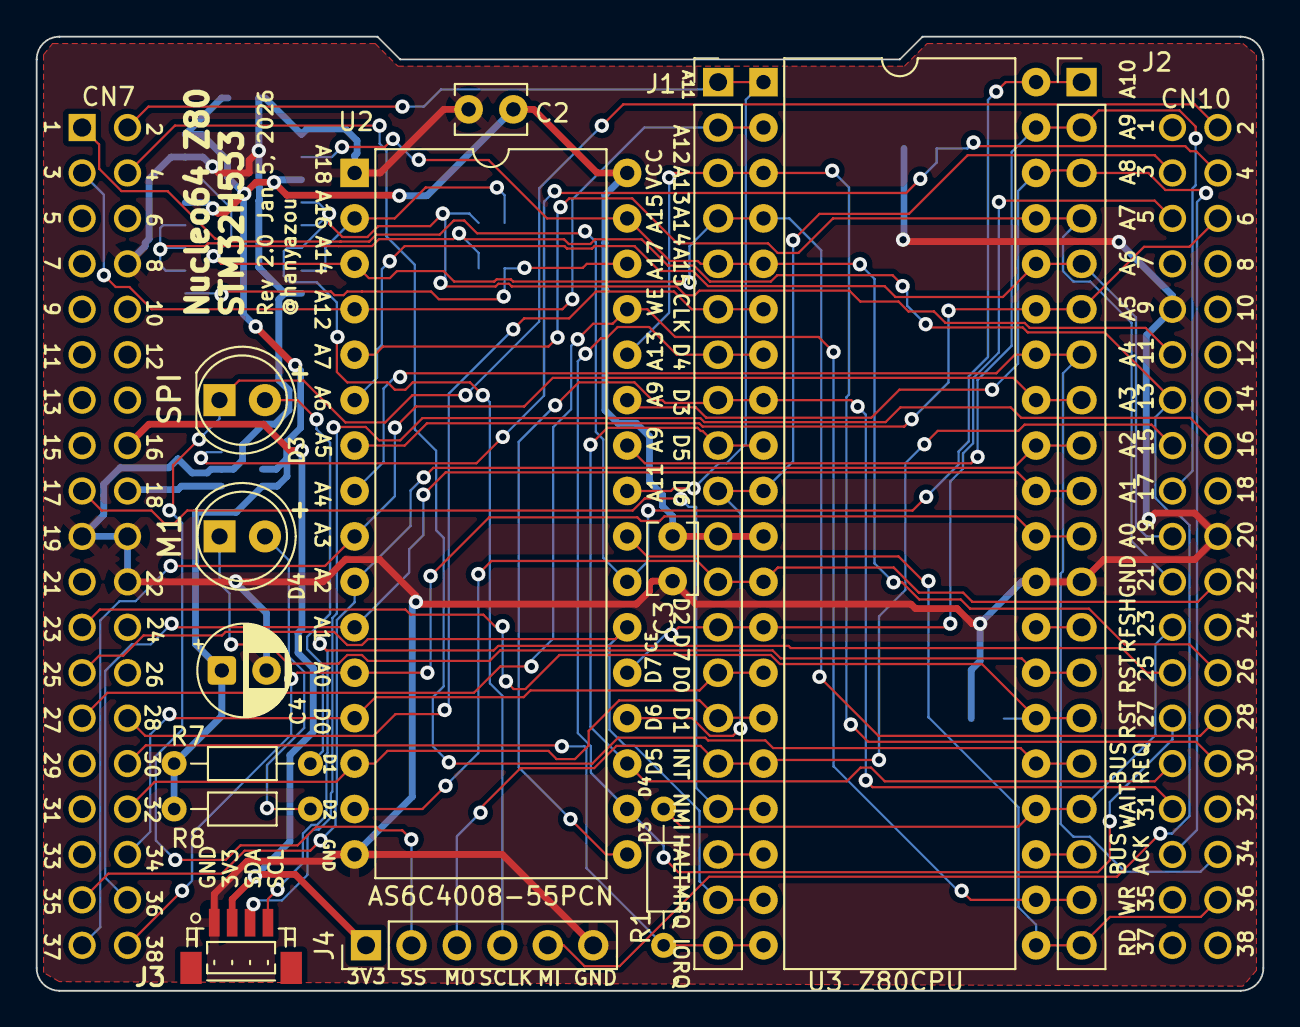
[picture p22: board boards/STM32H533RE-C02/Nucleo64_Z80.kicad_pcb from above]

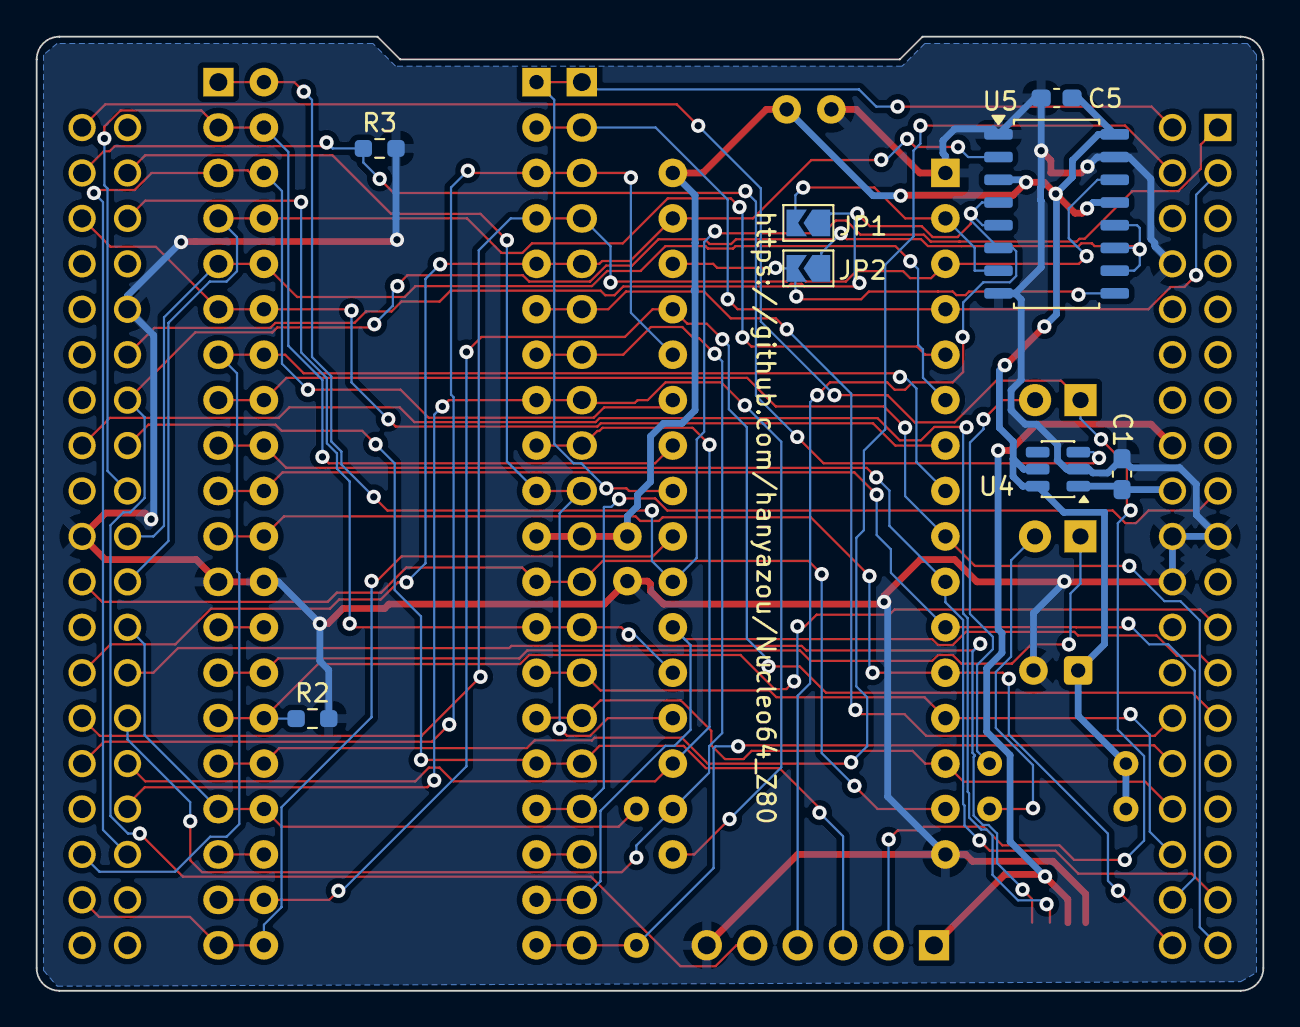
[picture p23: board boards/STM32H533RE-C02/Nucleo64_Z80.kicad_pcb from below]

Board: 2 copper layers, 68.6 x 53.3 mm, 23 parts (8 on the bottom side), 52 nets.

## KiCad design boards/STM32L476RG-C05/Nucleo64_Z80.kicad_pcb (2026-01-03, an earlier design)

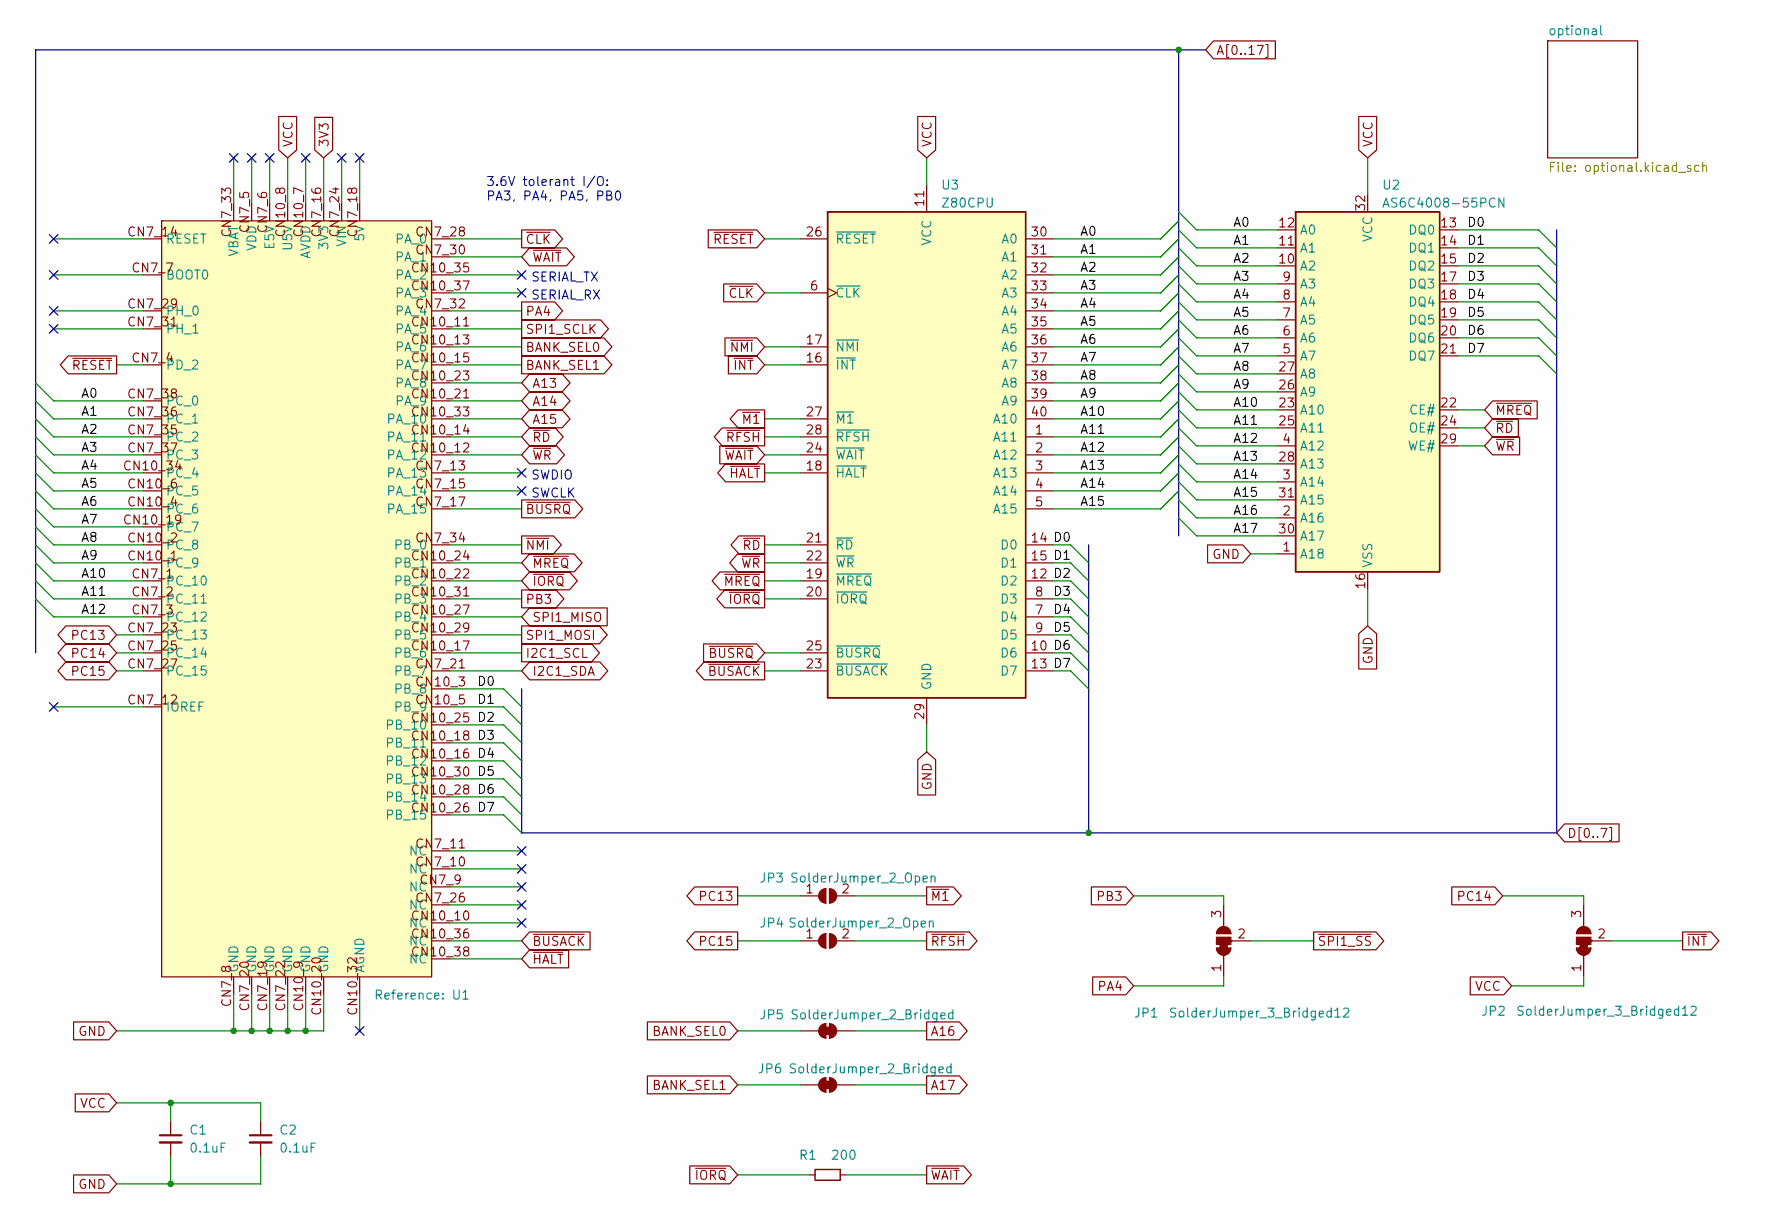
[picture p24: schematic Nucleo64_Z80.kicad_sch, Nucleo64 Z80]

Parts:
C1, C2: 0.1uF; C_Disc_D3.8mm_W2.6mm_P2.50mm
JP1, JP2: SolderJumper_3_Bridged12; SolderJumper-3_P1.3mm_Bridged12_RoundedPad1.0x1.5mm_NumberL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
JP3, JP4: SolderJumper_2_Open; SolderJumper-2_P1.3mm_Open_RoundedPad1.0x1.5mm
JP5, JP6: SolderJumper_2_Bridged; SolderJumper-2_P1.3mm_Bridged_RoundedPad1.0x1.5mm
R1: 200; R_Axial_DIN0204_L3.6mm_D1.6mm_P7.62mm_Horizontal
U1: NUCLEO64_morpho
U2: AS6C4008-55PCN; DIP-32_W15.24mm
U3: Z80CPU; DIP-40_W15.24mm

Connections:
3V3: U1.CN7_16 (3V3); also elsewhere on the board
A0: U1.CN7_38 (PC_0), U2.12 (A0), U3.30 (A0); also elsewhere on the board
A1: U1.CN7_36 (PC_1), U2.11 (A1), U3.31 (A1); also elsewhere on the board
A2: U1.CN7_35 (PC_2), U2.10 (A2), U3.32 (A2); also elsewhere on the board
A3: U1.CN7_37 (PC_3), U2.9 (A3), U3.33 (A3); also elsewhere on the board
A4: U1.CN10_34 (PC_4), U2.8 (A4), U3.34 (A4); also elsewhere on the board
A5: U1.CN10_6 (PC_5), U2.7 (A5), U3.35 (A5); also elsewhere on the board
A6: U1.CN10_4 (PC_6), U2.6 (A6), U3.36 (A6); also elsewhere on the board
A7: U1.CN10_19 (PC_7), U2.5 (A7), U3.37 (A7); also elsewhere on the board
A8: U1.CN10_2 (PC_8), U2.27 (A8), U3.38 (A8); also elsewhere on the board
A9: U1.CN10_1 (PC_9), U2.26 (A9), U3.39 (A9); also elsewhere on the board
A10: U1.CN7_1 (PC_10), U2.23 (A10), U3.40 (A10); also elsewhere on the board
A11: U1.CN7_2 (PC_11), U2.25 (A11), U3.1 (A11); also elsewhere on the board
A12: U1.CN7_3 (PC_12), U2.4 (A12), U3.2 (A12); also elsewhere on the board
A13: U1.CN10_23 (PA_8), U2.28 (A13), U3.3 (A13); also elsewhere on the board
A14: U1.CN10_21 (PA_9), U2.3 (A14), U3.4 (A14); also elsewhere on the board
A15: U1.CN10_33 (PA_10), U2.31 (A15), U3.5 (A15); also elsewhere on the board
A16: JP5.2 (B), U2.2 (A16); also elsewhere on the board
A17: JP6.2 (B), U2.30 (A17); also elsewhere on the board
BANK_SEL0: JP5.1 (A), U1.CN10_13 (PA_6); also elsewhere on the board
BANK_SEL1: JP6.1 (A), U1.CN10_15 (PA_7); also elsewhere on the board
D0: U1.CN10_3 (PB_8), U2.13 (DQ0), U3.14 (D0); also elsewhere on the board
D1: U1.CN10_5 (PB_9), U2.14 (DQ1), U3.15 (D1); also elsewhere on the board
D2: U1.CN10_25 (PB_10), U2.15 (DQ2), U3.12 (D2); also elsewhere on the board
D3: U1.CN10_18 (PB_11), U2.17 (DQ3), U3.8 (D3); also elsewhere on the board
D4: U1.CN10_16 (PB_12), U2.18 (DQ4), U3.7 (D4); also elsewhere on the board
D5: U1.CN10_30 (PB_13), U2.19 (DQ5), U3.9 (D5); also elsewhere on the board
D6: U1.CN10_28 (PB_14), U2.20 (DQ6), U3.10 (D6); also elsewhere on the board
D7: U1.CN10_26 (PB_15), U2.21 (DQ7), U3.13 (D7); also elsewhere on the board
GND: C1.2, C2.2, U1.CN7_8 (GND), U1.CN7_19 (GND), U1.CN7_20 (GND), U1.CN7_22 (GND), U1.CN10_9 (GND), U1.CN10_20 (GND), U2.1 (A18), U2.16 (VSS), U3.29 (GND); also elsewhere on the board
I2C1_SCL: U1.CN10_17 (PB_6); also elsewhere on the board
I2C1_SDA: U1.CN7_21 (PB_7); also elsewhere on the board
PA4: JP1.1 (A), U1.CN7_32 (PA_4)
PB3: JP1.3 (B), U1.CN10_31 (PB_3)
PC13: JP3.1 (A), U1.CN7_23 (PC_13)
PC14: JP2.3 (B), U1.CN7_25 (PC_14)
PC15: JP4.1 (A), U1.CN7_27 (PC_15)
SPI1_MISO: U1.CN10_27 (PB_4); also elsewhere on the board
SPI1_MOSI: U1.CN10_29 (PB_5); also elsewhere on the board
SPI1_SCLK: U1.CN10_11 (PA_5); also elsewhere on the board
VCC: C1.1, C2.1, JP2.1 (A), U1.CN10_8 (U5V), U2.32 (VCC), U3.11 (VCC); also elsewhere on the board
~BUSACK: U1.CN10_36 (NC), U3.23 (~BUSACK); also elsewhere on the board
~BUSRQ: U1.CN7_17 (PA_15), U3.25 (~BUSRQ); also elsewhere on the board
~CLK: U1.CN7_28 (PA_0), U3.6 (~CLK); also elsewhere on the board
~HALT: U1.CN10_38 (NC), U3.18 (~HALT); also elsewhere on the board
~INT: JP2.2 (C), U3.16 (~INT); also elsewhere on the board
~IORQ: R1.2, U1.CN10_22 (PB_2), U3.20 (~IORQ); also elsewhere on the board
~M1: JP3.2 (B), U3.27 (~M1); also elsewhere on the board
~MREQ: U1.CN10_24 (PB_1), U2.22 (CE#), U3.19 (~MREQ); also elsewhere on the board
~NMI: U1.CN7_34 (PB_0), U3.17 (~NMI); also elsewhere on the board
~RD: U1.CN10_14 (PA_11), U2.24 (OE#), U3.21 (~RD); also elsewhere on the board
~RESET: U1.CN7_4 (PD_2), U3.26 (~RESET); also elsewhere on the board
~RFSH: JP4.2 (B), U3.28 (~RFSH); also elsewhere on the board
~SPI1_SS: JP1.2 (C); also elsewhere on the board
~WAIT: R1.1, U1.CN7_30 (PA_1), U3.24 (~WAIT); also elsewhere on the board
~WR: U1.CN10_12 (PA_12), U2.29 (WE#), U3.22 (~WR); also elsewhere on the board

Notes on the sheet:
SWDIO
SERIAL_RX
SERIAL_TX
SWCLK
3.6V tolerant I/O: PA3, PA4, PA5, PB0

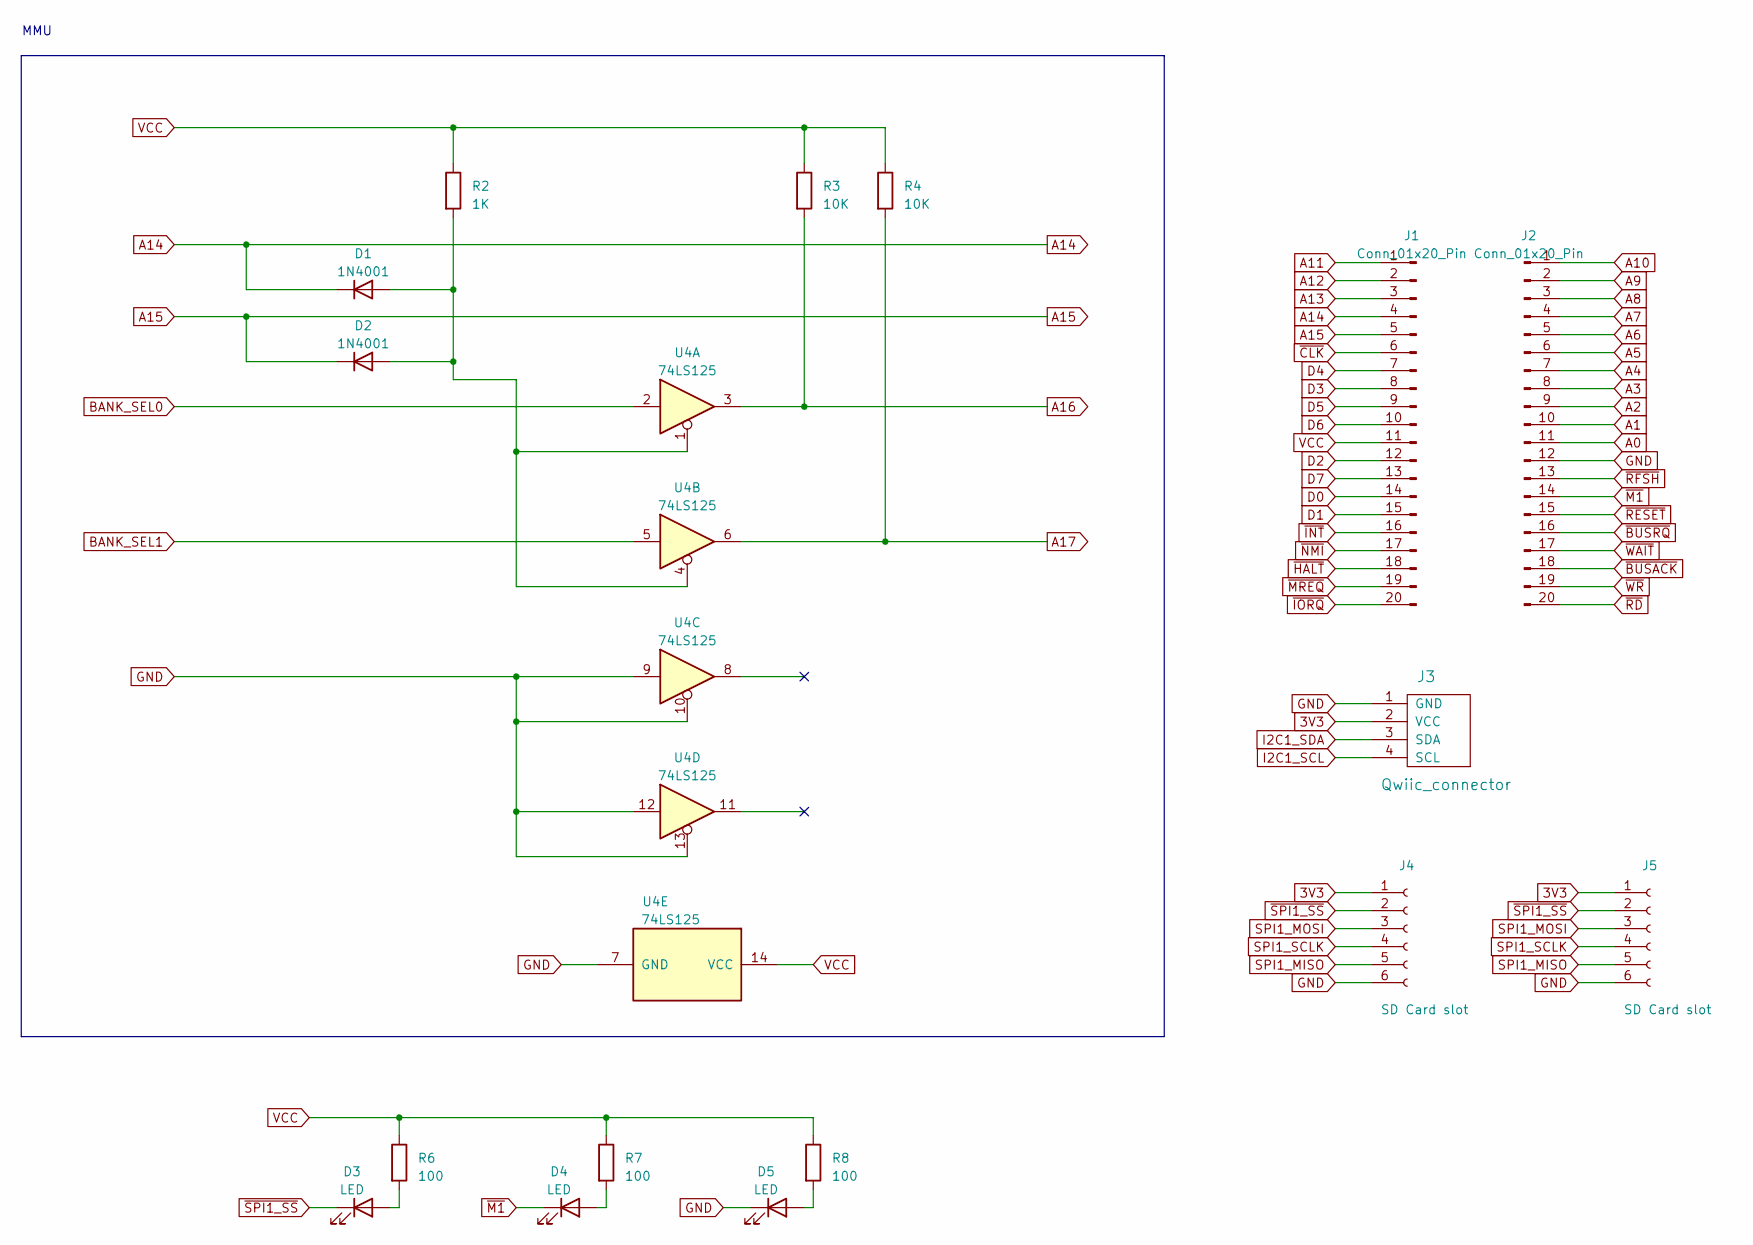
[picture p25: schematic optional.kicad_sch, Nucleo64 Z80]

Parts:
D1, D2: 1N4001; D_0805_2012Metric_Pad1.15x1.40mm_HandSolder
D3, D4, D5: LED; LED_D5.0mm
J1, J2: Conn_01x20_Pin; PinHeader_1x20_P2.54mm_Vertical
J3: Qwiic_connector; Qwiic_I2C_1.00mm_4pin
J4, J5: SD Card slot; PinHeader_1x06_P2.54mm_Vertical
R2: 1K; R_0805_2012Metric_Pad1.20x1.40mm_HandSolder
R3, R4: 10K; R_0805_2012Metric_Pad1.20x1.40mm_HandSolder
R6, R7, R8: 100; R_Axial_DIN0204_L3.6mm_D1.6mm_P7.62mm_Horizontal
U4: 74LS125; SSOP-14_5.3x6.2mm_P0.65mm

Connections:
3V3: J3.2 (VCC), J4.1, J5.1; also elsewhere on the board
A0: J2.11; also elsewhere on the board
A1: J2.10; also elsewhere on the board
A2: J2.9; also elsewhere on the board
A3: J2.8; also elsewhere on the board
A4: J2.7; also elsewhere on the board
A5: J2.6; also elsewhere on the board
A6: J2.5; also elsewhere on the board
A7: J2.4; also elsewhere on the board
A8: J2.3; also elsewhere on the board
A9: J2.2; also elsewhere on the board
A10: J2.1; also elsewhere on the board
A11: J1.1; also elsewhere on the board
A12: J1.2; also elsewhere on the board
A13: J1.3; also elsewhere on the board
A14: D1.1 (K), J1.4; also elsewhere on the board
A15: D2.1 (K), J1.5; also elsewhere on the board
A16: R3.2, U4.3; also elsewhere on the board
A17: R4.2, U4.6; also elsewhere on the board
BANK_SEL0: U4.2; also elsewhere on the board
BANK_SEL1: U4.5; also elsewhere on the board
D0: J1.14; also elsewhere on the board
D1: J1.15; also elsewhere on the board
D2: J1.12; also elsewhere on the board
D3: J1.8; also elsewhere on the board
D4: J1.7; also elsewhere on the board
D5: J1.9; also elsewhere on the board
D6: J1.10; also elsewhere on the board
D7: J1.13; also elsewhere on the board
GND: D5.1 (K), J2.12, J3.1 (GND), J4.6, J5.6, U4.7 (GND), U4.9, U4.10, U4.12, U4.13; also elsewhere on the board
I2C1_SCL: J3.4 (SCL); also elsewhere on the board
I2C1_SDA: J3.3 (SDA); also elsewhere on the board
unnamed: D1.2 (A), D2.2 (A), R2.2, U4.1, U4.4
unnamed: D3.2 (A), R6.2
unnamed: D4.2 (A), R7.2
unnamed: D5.2 (A), R8.2
SPI1_MISO: J4.5, J5.5; also elsewhere on the board
SPI1_MOSI: J4.3, J5.3; also elsewhere on the board
SPI1_SCLK: J4.4, J5.4; also elsewhere on the board
VCC: J1.11, R2.1, R3.1, R4.1, R6.1, R7.1, R8.1, U4.14 (VCC); also elsewhere on the board
~BUSACK: J2.18; also elsewhere on the board
~BUSRQ: J2.16; also elsewhere on the board
~CLK: J1.6; also elsewhere on the board
~HALT: J1.18; also elsewhere on the board
~INT: J1.16; also elsewhere on the board
~IORQ: J1.20; also elsewhere on the board
~M1: D4.1 (K), J2.14; also elsewhere on the board
~MREQ: J1.19; also elsewhere on the board
~NMI: J1.17; also elsewhere on the board
~RD: J2.20; also elsewhere on the board
~RESET: J2.15; also elsewhere on the board
~RFSH: J2.13; also elsewhere on the board
~SPI1_SS: D3.1 (K), J4.2, J5.2; also elsewhere on the board
~WAIT: J2.17; also elsewhere on the board
~WR: J2.19; also elsewhere on the board

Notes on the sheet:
MMU

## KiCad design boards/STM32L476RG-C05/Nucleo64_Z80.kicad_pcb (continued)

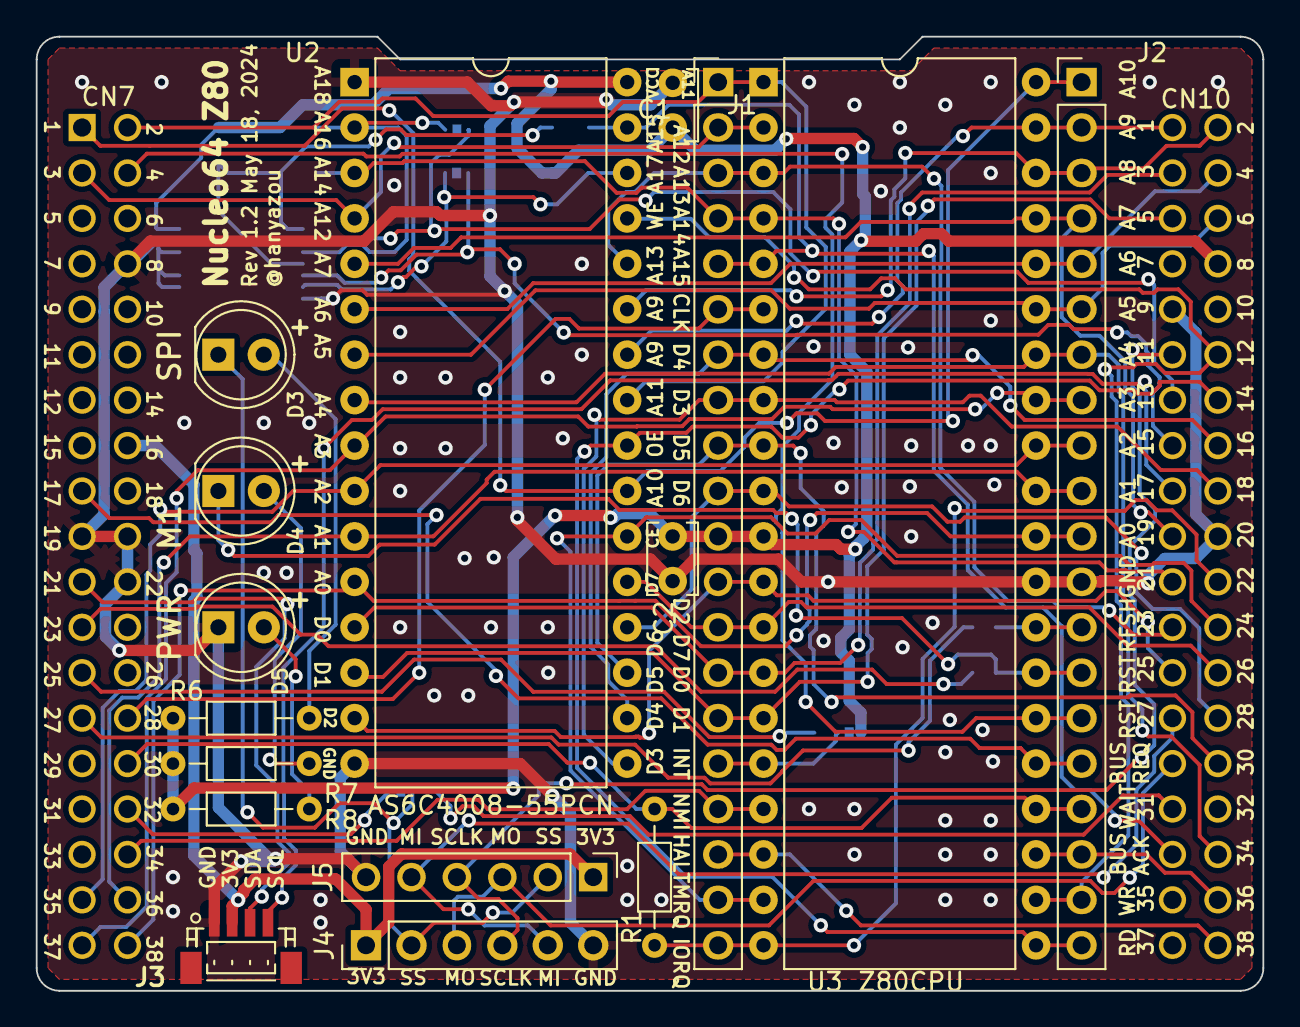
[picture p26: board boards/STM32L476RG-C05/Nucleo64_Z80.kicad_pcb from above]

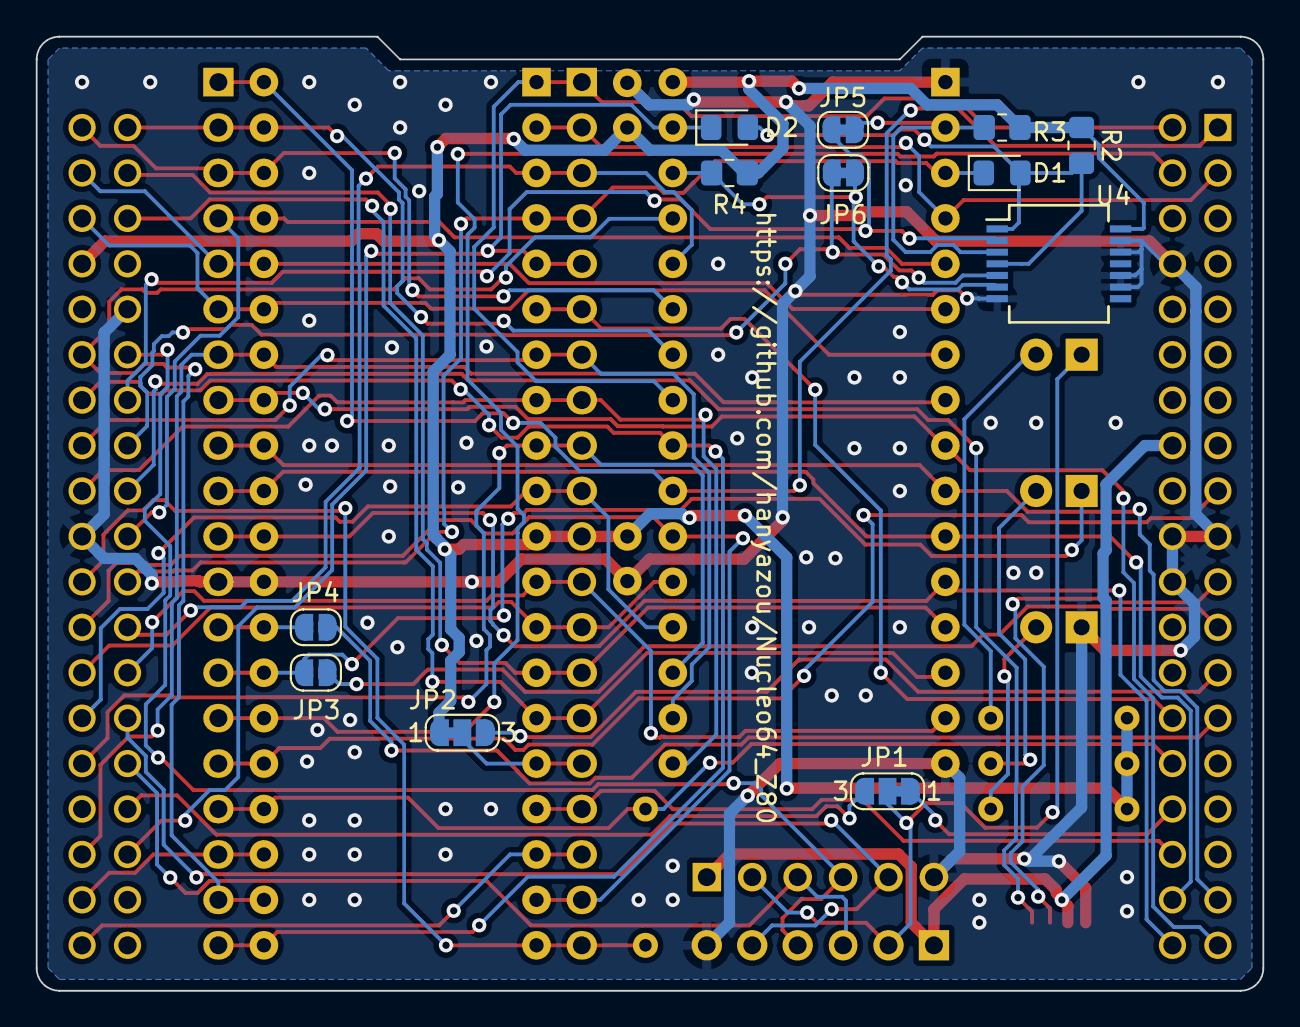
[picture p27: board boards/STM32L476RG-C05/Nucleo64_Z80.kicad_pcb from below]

Board: 2 copper layers, 68.6 x 53.3 mm, 29 parts (12 on the bottom side), 60 nets.

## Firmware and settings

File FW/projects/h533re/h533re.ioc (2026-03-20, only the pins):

Mcu.UserName=STM32H533RETx
PA0.Signal=S_TIM2_CH1
PA1.GPIO_Label=Z80_IOREQ
PA1.Signal=GPIO_Input
PA10.GPIO_Label=Z80_PWR_EN
PA10.Signal=GPIO_Output
PA11.Signal=USB_DM
PA12.Signal=USB_DP
PA15(JTDI).GPIO_Label=Z80_NMI
PA15(JTDI).Signal=GPIO_Input
PA2.Signal=USART2_TX
PA3.Signal=USART2_RX
PA4.GPIO_Label=USB_FS_PWR_EN
PA4.Signal=GPIO_Output
PA5.GPIO_Label=BANK_SEL0
PA5.Signal=SPI1_SCK
PA6.GPIO_Label=BANK_SEL1
PA6.Signal=SPI1_MISO
PA7.GPIO_Label=Z80_INT
PA7.Signal=SPI1_MOSI
PA8.GPIO_Label=Z80_WAIT
PA8.Signal=GPIO_Input
PA9.GPIO_Label=SPI_SS
PA9.Signal=GPIO_Output
PB0.GPIO_Label=Z80_D0
PB0.Signal=GPIO_Input
PB1.GPIO_Label=Z80_D1
PB1.Signal=GPIO_Input
PB10.Signal=I2C2_SCL
PB12.Signal=I2C2_SDA
PB13.GPIO_Label=Z80_A13
PB13.Signal=GPIO_Input
PB14.GPIO_Label=Z80_A14
PB14.Signal=GPIO_Input
PB15.GPIO_Label=Z80_A15
PB15.Signal=GPIO_Input
PB2.GPIO_Label=Z80_D2
PB2.Signal=GPIO_Input
PB3(JTDO/TRACESWO).GPIO_Label=Z80_D3
PB3(JTDO/TRACESWO).Signal=GPIO_Input
PB4(NJTRST).GPIO_Label=Z80_D4
PB4(NJTRST).Signal=GPIO_Input
PB5.GPIO_Label=Z80_D5
PB5.Signal=GPIO_Input
PB6.GPIO_Label=Z80_D6
PB6.Signal=GPIO_Input
PB7.GPIO_Label=Z80_D7
PB7.Signal=GPIO_Input
PB8.GPIO_Label=Z80_RD
PB8.Signal=GPIO_Input
PC0.GPIO_Label=Z80_A0
PC0.Signal=GPIO_Input
PC1.GPIO_Label=Z80_A1
PC1.Signal=GPIO_Input
PC10.GPIO_Label=Z80_A10
PC10.Signal=GPIO_Input
PC11.GPIO_Label=Z80_A11
PC11.Signal=GPIO_Input
PC12.GPIO_Label=Z80_A12
PC12.Signal=GPIO_Input
PC13.GPIO_Label=Z80_RESET
PC13.Signal=GPIO_Input
PC14-OSC32_IN(OSC32_IN).GPIO_Label=Z80_MEMRQ
PC14-OSC32_IN(OSC32_IN).Signal=GPIO_Input
PC15-OSC32_OUT(OSC32_OUT).GPIO_Label=Z80_WR
PC15-OSC32_OUT(OSC32_OUT).Signal=GPIO_Input
PC2.GPIO_Label=Z80_A2
PC2.Signal=GPIO_Input
PC3.GPIO_Label=Z80_A3
PC3.Signal=GPIO_Input
PC4.GPIO_Label=Z80_A4
PC4.Signal=GPIO_Input
PC5.GPIO_Label=Z80_A5
PC5.Signal=GPIO_Input
PC6.GPIO_Label=Z80_A6
PC6.Signal=GPIO_Input
PC7.GPIO_Label=Z80_A7
PC7.Signal=GPIO_Input
PC8.GPIO_Label=Z80_A8
PC8.Signal=GPIO_Input
PC9.GPIO_Label=Z80_A9
PC9.Signal=GPIO_Input
PD2.GPIO_Label=Z80_BUSRQ
PD2.Signal=GPIO_Input

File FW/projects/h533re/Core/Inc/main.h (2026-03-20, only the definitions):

#define Z80_RESET_Pin GPIO_PIN_13
#define Z80_RESET_GPIO_Port GPIOC
#define Z80_MEMRQ_Pin GPIO_PIN_14
#define Z80_MEMRQ_GPIO_Port GPIOC
#define Z80_WR_Pin GPIO_PIN_15
#define Z80_WR_GPIO_Port GPIOC
#define Z80_A0_Pin GPIO_PIN_0
#define Z80_A0_GPIO_Port GPIOC
#define Z80_A1_Pin GPIO_PIN_1
#define Z80_A1_GPIO_Port GPIOC
#define Z80_A2_Pin GPIO_PIN_2
#define Z80_A2_GPIO_Port GPIOC
#define Z80_A3_Pin GPIO_PIN_3
#define Z80_A3_GPIO_Port GPIOC
#define Z80_IOREQ_Pin GPIO_PIN_1
#define Z80_IOREQ_GPIO_Port GPIOA
#define USB_FS_PWR_EN_Pin GPIO_PIN_4
#define USB_FS_PWR_EN_GPIO_Port GPIOA
#define BANK_SEL0_Pin GPIO_PIN_5
#define BANK_SEL0_GPIO_Port GPIOA
#define BANK_SEL1_Pin GPIO_PIN_6
#define BANK_SEL1_GPIO_Port GPIOA
#define Z80_INT_Pin GPIO_PIN_7
#define Z80_INT_GPIO_Port GPIOA
#define Z80_A4_Pin GPIO_PIN_4
#define Z80_A4_GPIO_Port GPIOC
#define Z80_A5_Pin GPIO_PIN_5
#define Z80_A5_GPIO_Port GPIOC
#define Z80_D0_Pin GPIO_PIN_0
#define Z80_D0_GPIO_Port GPIOB
#define Z80_D1_Pin GPIO_PIN_1
#define Z80_D1_GPIO_Port GPIOB
#define Z80_D2_Pin GPIO_PIN_2
#define Z80_D2_GPIO_Port GPIOB
#define Z80_A13_Pin GPIO_PIN_13
#define Z80_A13_GPIO_Port GPIOB
#define Z80_A14_Pin GPIO_PIN_14
#define Z80_A14_GPIO_Port GPIOB
#define Z80_A15_Pin GPIO_PIN_15
#define Z80_A15_GPIO_Port GPIOB
#define Z80_A6_Pin GPIO_PIN_6
#define Z80_A6_GPIO_Port GPIOC
#define Z80_A7_Pin GPIO_PIN_7
#define Z80_A7_GPIO_Port GPIOC
#define Z80_A8_Pin GPIO_PIN_8
#define Z80_A8_GPIO_Port GPIOC
#define Z80_A9_Pin GPIO_PIN_9
#define Z80_A9_GPIO_Port GPIOC
#define Z80_WAIT_Pin GPIO_PIN_8
#define Z80_WAIT_GPIO_Port GPIOA
#define SPI_SS_Pin GPIO_PIN_9
#define SPI_SS_GPIO_Port GPIOA
#define Z80_PWR_EN_Pin GPIO_PIN_10
#define Z80_PWR_EN_GPIO_Port GPIOA
#define Z80_NMI_Pin GPIO_PIN_15
#define Z80_NMI_GPIO_Port GPIOA
#define Z80_A10_Pin GPIO_PIN_10
#define Z80_A10_GPIO_Port GPIOC
#define Z80_A11_Pin GPIO_PIN_11
#define Z80_A11_GPIO_Port GPIOC
#define Z80_A12_Pin GPIO_PIN_12
#define Z80_A12_GPIO_Port GPIOC
#define Z80_BUSRQ_Pin GPIO_PIN_2
#define Z80_BUSRQ_GPIO_Port GPIOD
#define Z80_D3_Pin GPIO_PIN_3
#define Z80_D3_GPIO_Port GPIOB
#define Z80_D4_Pin GPIO_PIN_4
#define Z80_D4_GPIO_Port GPIOB
#define Z80_D5_Pin GPIO_PIN_5
#define Z80_D5_GPIO_Port GPIOB
#define Z80_D6_Pin GPIO_PIN_6
#define Z80_D6_GPIO_Port GPIOB
#define Z80_D7_Pin GPIO_PIN_7
#define Z80_D7_GPIO_Port GPIOB
#define Z80_RD_Pin GPIO_PIN_8
#define Z80_RD_GPIO_Port GPIOB

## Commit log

2026-01-03 boards: Rename kicad to STM32L476RG-C05
    [Nucleo64_Z80.kicad_pcb, Nucleo64_Z80.kicad_sch, optional.kicad_sch]
2026-01-04 boards: Add STM32H533RE-C02 (copy of STM32L476RG-C05)
    [Nucleo64_Z80.kicad_pcb, Nucleo64_Z80.kicad_sch, optional.kicad_sch]
2026-01-05 stm32h533re: Fix schematics
    [Nucleo64_Z80.kicad_sch, optional.kicad_sch]
2026-01-05 stm32h533re: Fix PCB layout
    [Nucleo64_Z80.kicad_pcb, Nucleo64_Z80.kicad_sch, optional.kicad_sch]
2026-01-05 stm32h533re: Add gerber archive Nucleo64_Z80-2.0.zip
2026-01-31 fw: h533_usb_host_test: Add FileX, ThreadX and USBX
2026-01-31 fw: h533_usb_host_test: Fix USBX configuration parameters
    [h533_usb_host_test.ioc]
2026-02-07 tools: zasm: Ignore dirty state of zasm submodule on case-insensitive filesystems
    The zasm submodule contains files that differ only by case (e.g. Hello.asm vs hello.asm),
    which shows up as modified on macOS default case-insensitive filesystems.
    Set submodule ignore=dirty to keep git status clean.
2026-02-07 fw: h533re: Configure system clock and peripherals for board bring-up
    * USART2
    115200 8N1
    NVIC enable global interrupt
    GPIO PA2 USART2 TX
    GPIO PA3 USART2 RX
    * System Core
    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
2026-02-08 fw: h533re: Enable printf() using USART2 debug serial
2026-02-08 fw: h533re: Fix USBX configuration parameters
    [h533re.ioc]
2026-02-08 fw: nucleo64_z80: Add main thread to call nucleo64_z80 main routine
2026-02-08 fw: nucleo64_z80: Add z80 (copy of board_test)
2026-02-15 fw: nucleo64_z80: Add mem_init() to probe Z80 RAM and verify bank mapping
2026-02-15 fw: nucleo64_z80: Separate UART-related code from util.c into uart.c
2026-02-15 fw: h533re: Enable SPI for GPIO-shared pins (additional setup required)
2026-02-15 fw: h533re: Call sd_spi_start() to allow SPI pins to be shared with GPIO
2026-02-15 fw: h533re: Enable SPI for GPIO-shared pins (additional setup required) (fixed)
    [h533re.ioc, main.c]
2026-02-15 fw: nucleo64_z80: Import FatFs from STM32L476 sdcard_test project as-is
2026-02-15 fw: nucleo64_z80: Change Z80 pin init/deinit API to acquire/release with saved state
2026-02-15 fw: nucleo64_z80: uart: Fix getchar() blocking by making _read() wait for RX data
    [uart.c]
2026-02-21 fw: nucleo64_z80: Add mmu_bank_*() prototype to z80.h
2026-02-21 fw: nucleo64_z80: Fix z80_io to boot CP/M
    [z80_io.c]
2026-02-21 fw: nucleo64_z80: Change UART_CREG value to Z80-Simulator style
2026-02-21 fw: nucleo64_z80: Initialize Z80 INT/NMI pins to inactive to prevent spurious interrupts
2026-03-20 Move old STM32 projects into projects folder

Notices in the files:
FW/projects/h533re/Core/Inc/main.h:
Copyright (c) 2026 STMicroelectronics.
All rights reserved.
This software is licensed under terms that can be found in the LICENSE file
